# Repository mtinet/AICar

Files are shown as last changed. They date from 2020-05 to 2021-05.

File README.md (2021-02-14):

# AICar

### 아두이노 메가 사용 시 블루투스 내부 배선  
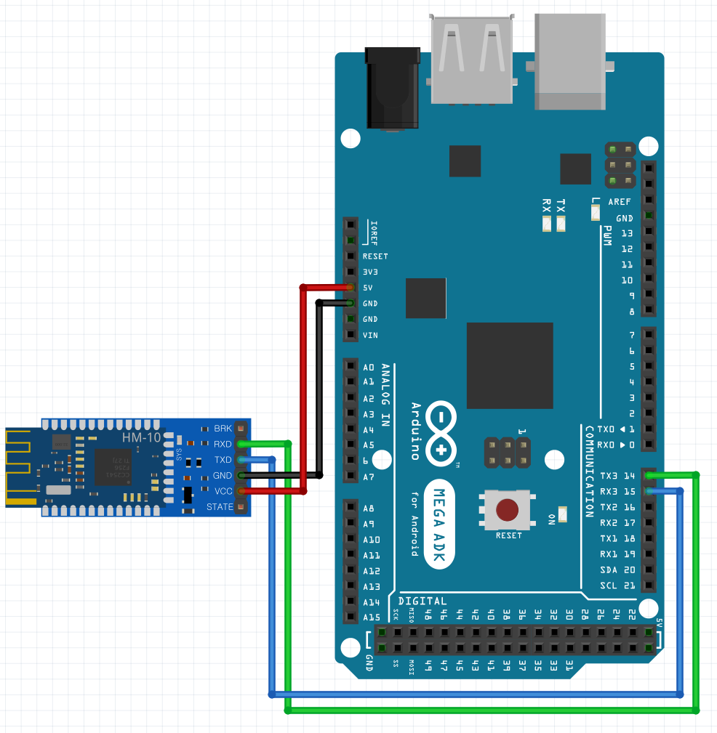
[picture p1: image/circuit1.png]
  

### 앱인벤터  
* [이미지 분류 학습](https://classifier.appinventor.mit.edu/)  
* [익스텐션 다운로드](https://mit-cml.github.io/extensions/) : PersonalImageClassifier, BLE 다운로드 받을 것  
* BLE 세팅 방법  
  
```
serviceUUID : 0000FFE0-0000-1000-8000-00805F9B34FB
name : 아두이노의 AT커맨드로 자기가 지정해 준 이름 입력  
```
* 아두이노 AT 커맨드 사용할 때 업로드 해야하는 코드, 블루투스 모듈(HM-10)이 다른 장치에 연결되지 않은 상태에서만 AT 커맨드가 적용됨, 아두이노의 시리얼 모니터 하단에 있는 옵션에서는 'line ending 없음' 또는 'Both NL & ER'을 선택하고, 통신속도는 9600보드레이트로 선택함  
```
void setup() {
  //통신 설정
  Serial.begin(9600); // 시리얼 통신(컴퓨터-USB케이블-아두이노 메가)
  Serial3.begin(9600); // 블루투스 통신(스마트폰 앱-블루투스-아두이노 메가)
  Serial.println("start");
}

void loop() {
  if (Serial3.available())        // 블루투스에서 데이터가 들어올 경우
    Serial.write(Serial3.read()); // 컴퓨터로 보냄
  if (Serial.available())         // 컴퓨터에서 데이터가 들어올 경우
    Serial3.write(Serial.read()); // 블루투스로 보냄
}
```

### 참고자료  
* [앱인벤터 코드 작성 참고자료](http://blog.naver.com/PostView.nhn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)  
* [앱인벤터, 아두이노 통신](http://sanguru.me/arduino009/) 
* [딕셔너리 결과물 보는 방법](http://ai2.appinventor.mit.edu/reference/blocks/dictionaries.html#get-value-at-key-path)  
* [BLE 세팅](http://www.martyncurrey.com/arduino-hm-10-and-app-inventor-2/#AI2)

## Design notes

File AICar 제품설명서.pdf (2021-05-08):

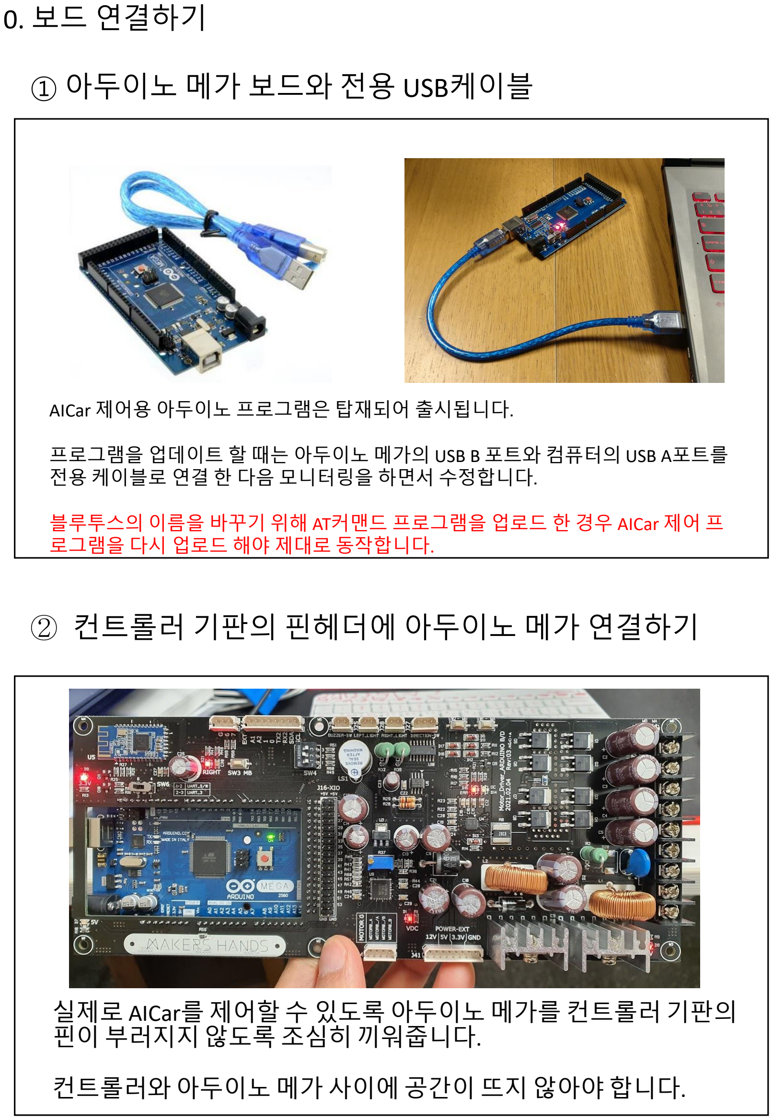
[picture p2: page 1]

### ② 컨트롤러 기판의 핀헤더에 아두이노 메가 연결하기

## ①②③④

0. 보드 연결하기

실제로 AICar를 제어할 수 있도록 아두이노 메가를 컨트롤러 기판의 핀이 부러지지 않도록 조심히 끼워줍니다.

컨트롤러와 아두이노 메가 사이에 공간이 뜨지 않아야 합니다.

AICar 제어용 아두이노 프로그램은 탑재되어 출시됩니다.

프로그램을 업데이트 할 때는 아두이노 메가의 USB B 포트와 컴퓨터의 USB A포트를 전용 케이블로 연결 한 다음 모니터링을 하면서 수정합니다.

블루투스의 이름을 바꾸기 위해 AT커맨드 프로그램을 업로드 한 경우 AICar 제어 프 로그램을 다시 업로드 해야 제대로 동작합니다.

### ① 아두이노 메가 보드와 전용 USB케이블

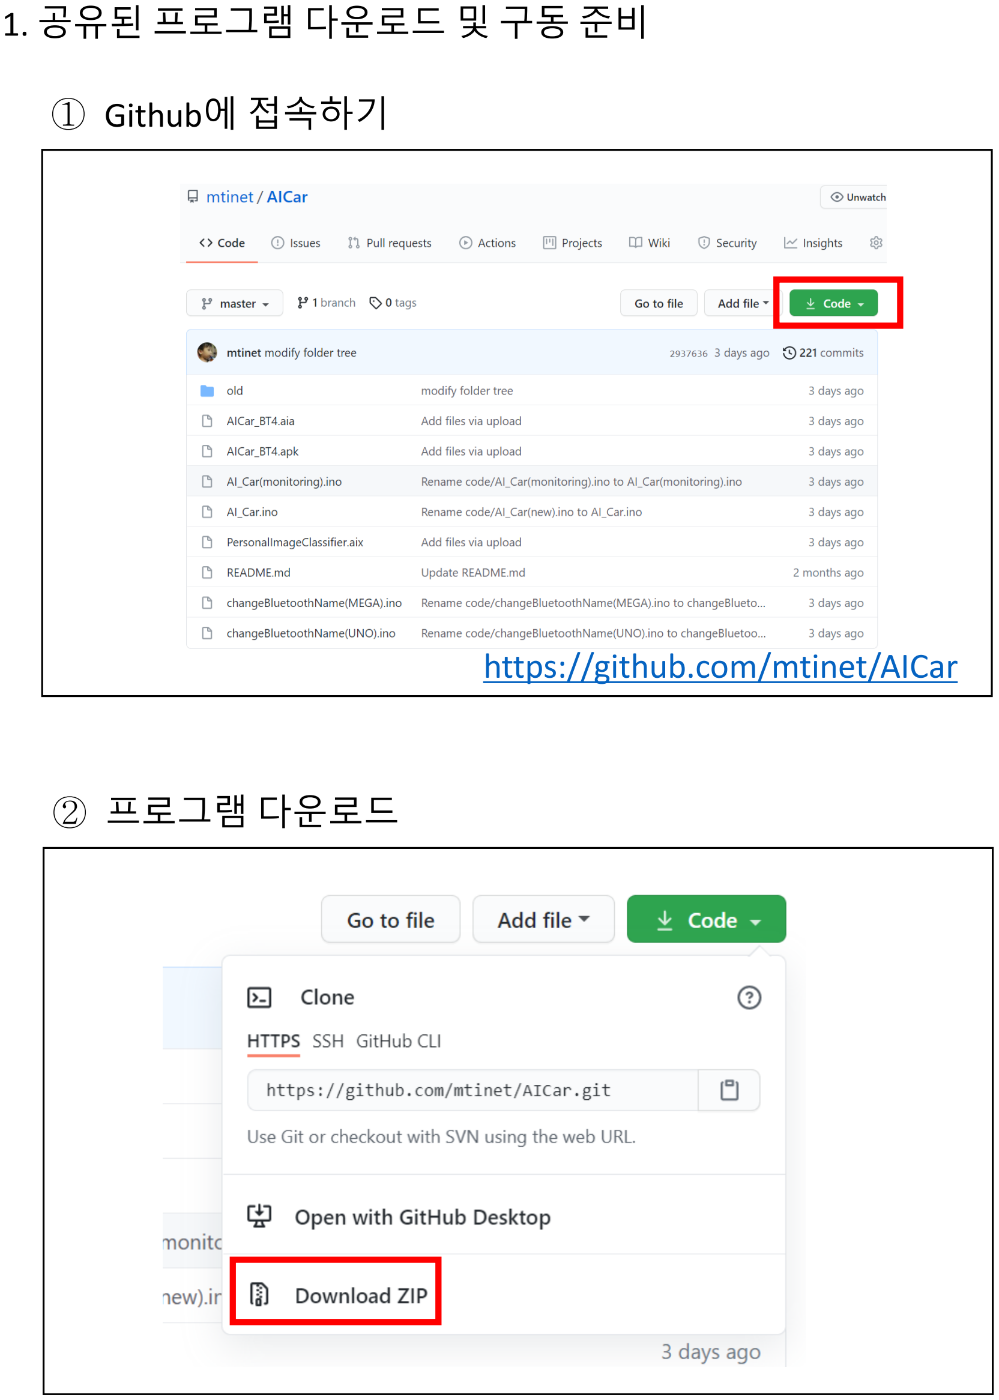
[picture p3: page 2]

① Github에 접속하기

### 1. 공유된 프로그램 다운로드 및 구동 준비

② 프로그램 다운로드

https://github.com/mtinet/AICar

### ③ 압축풀기

### ④ 바탕화면 선택

### 원하는 폴더를 지정하거나, 바탕화면을 선택함

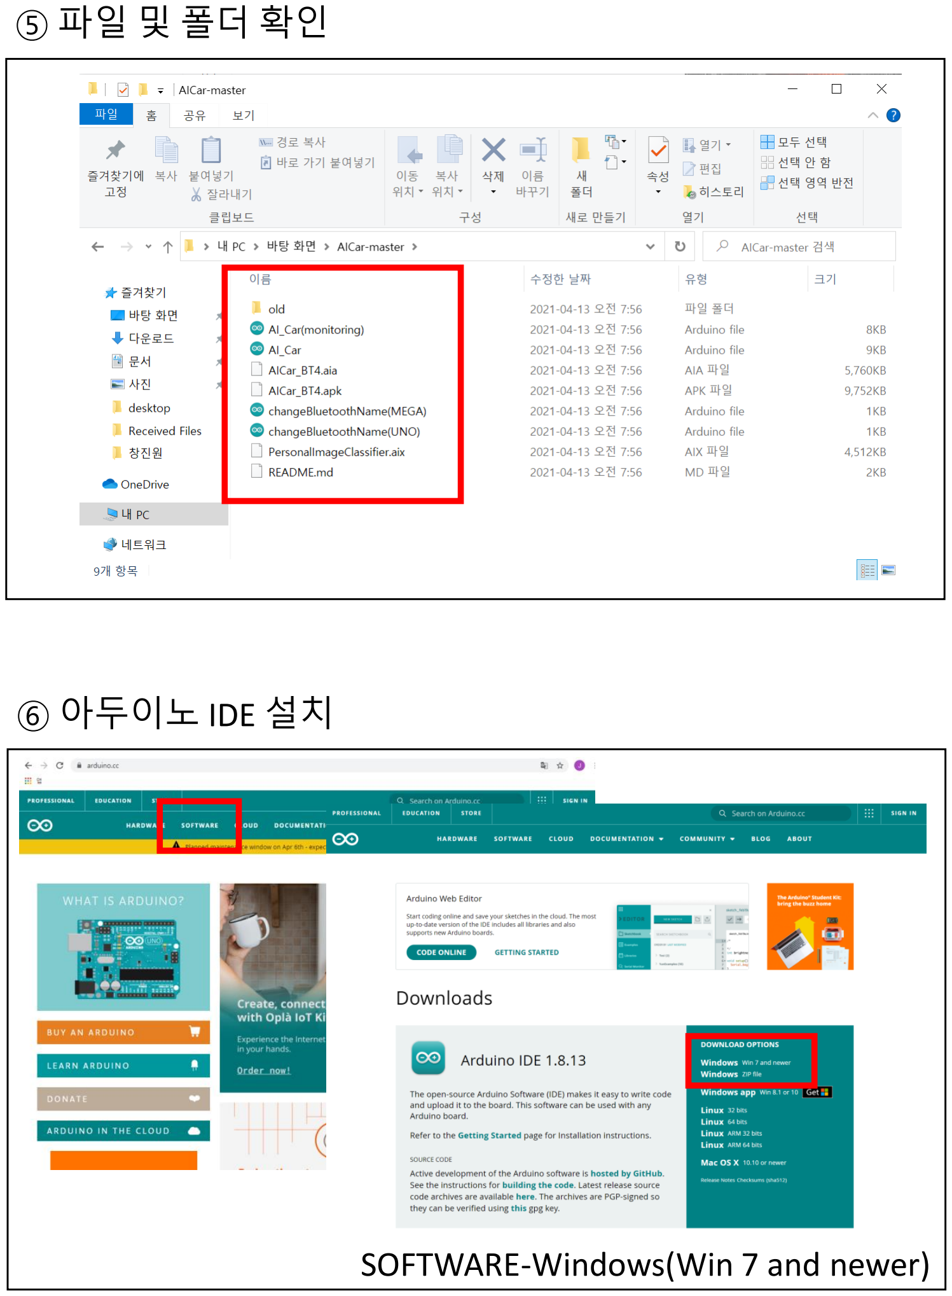
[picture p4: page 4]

### ⑤ 파일 및 폴더 확인

⑥ 아두이노 IDE 설치

SOFTWARE-Windows(Win 7 and newer)

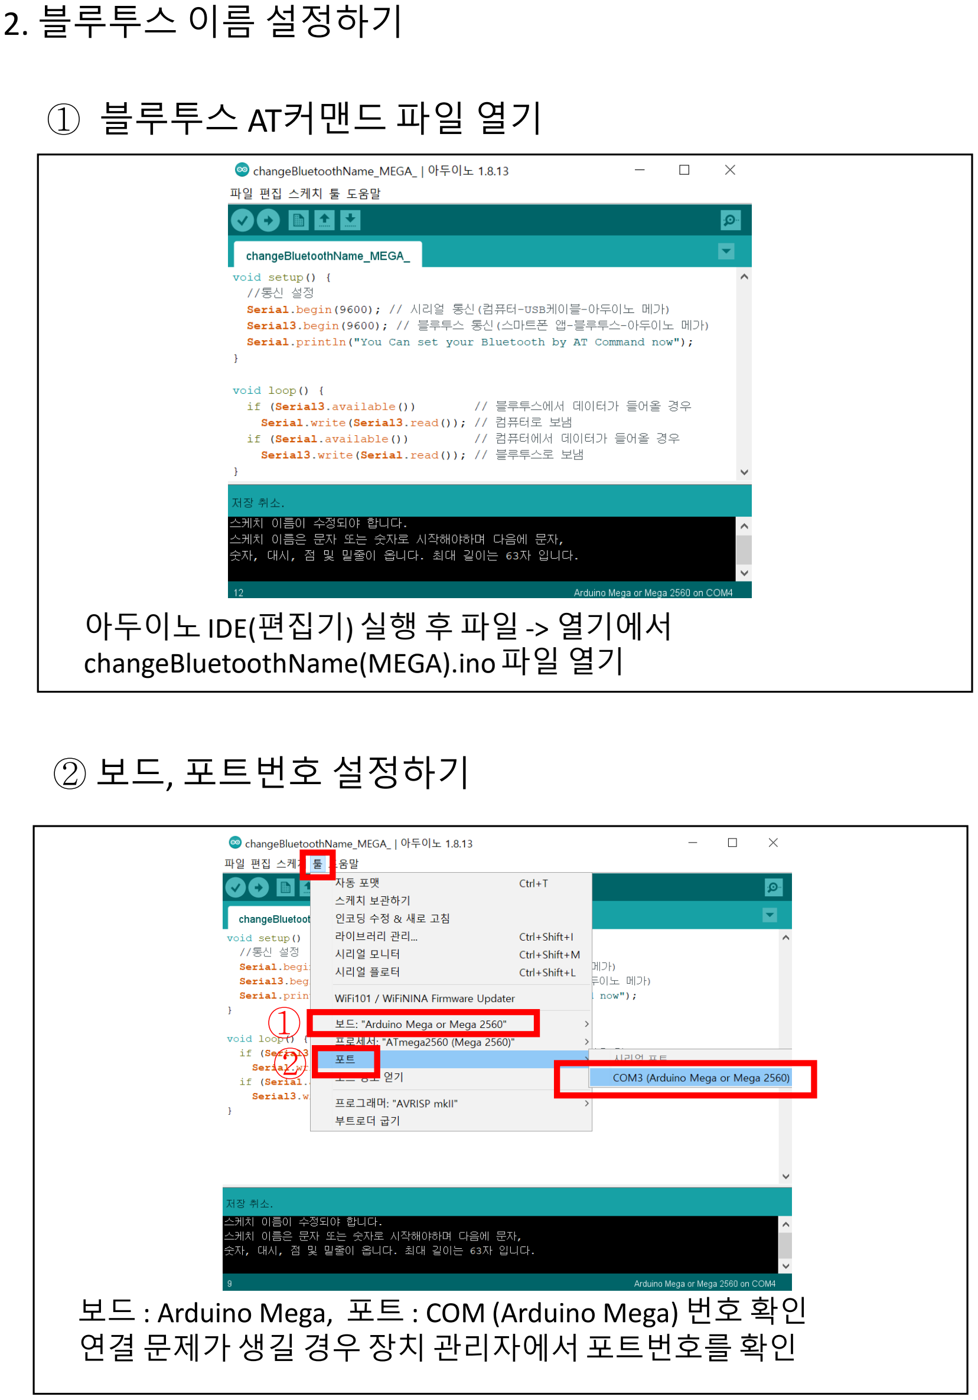
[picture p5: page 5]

### ① 블루투스 AT커맨드 파일 열기

② 보드, 포트번호 설정하기

보드 : Arduino Mega, 포트 : COM (Arduino Mega) 번호 확인 연결 문제가 생길 경우 장치 관리자에서 포트번호를 확인

②

①

아두이노 IDE(편집기) 실행 후 파일 -> 열기에서 changeBluetoothName(MEGA).ino 파일 열기

### 2. 블루투스 이름 설정하기

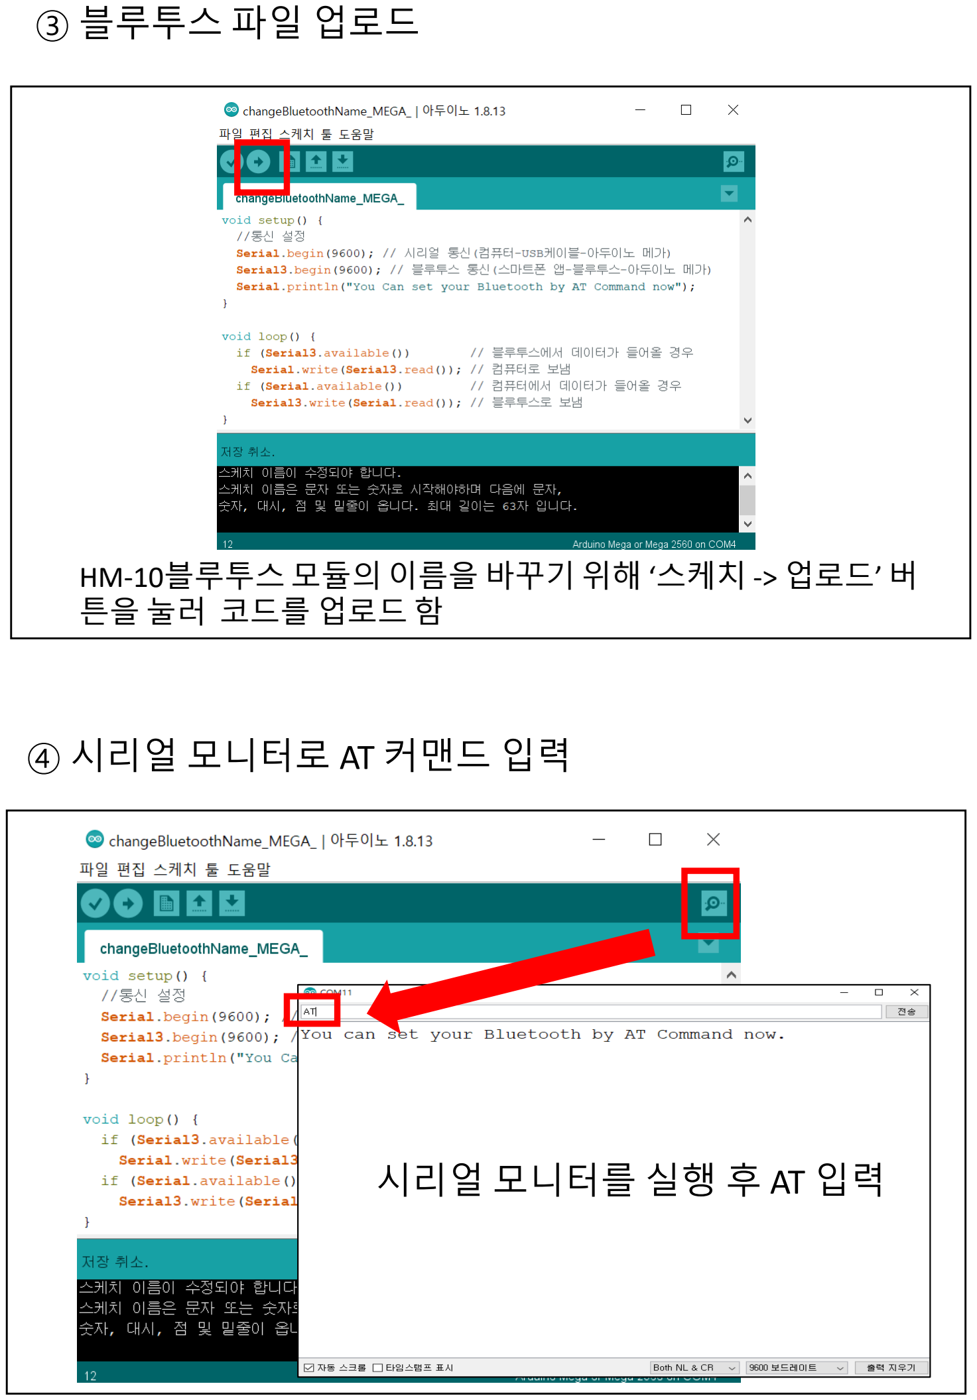
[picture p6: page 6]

③ 블루투스 파일 업로드

### ④ 시리얼 모니터로 AT 커맨드 입력

HM-10블루투스 모듈의 이름을 바꾸기 위해 ‘스케치 -> 업로드’ 버 튼을 눌러 코드를 업로드 함

### 시리얼 모니터를 실행 후 AT 입력

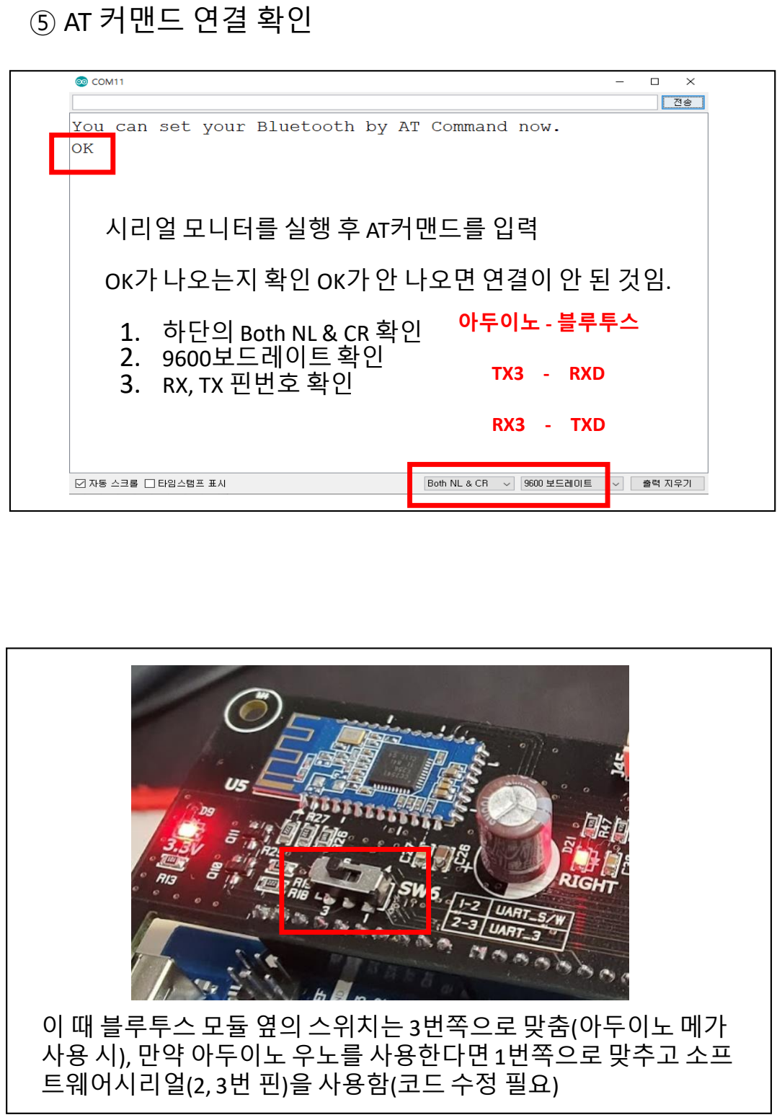
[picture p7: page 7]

### ⑤ AT 커맨드 연결 확인

시리얼 모니터를 실행 후 AT커맨드를 입력

OK가 나오는지 확인 OK가 안 나오면 연결이 안 된 것임.

1. 하단의 Both NL & CR 확인
2. 9600보드레이트 확인
3. RX, TX 핀번호 확인

이 때 블루투스 모듈 옆의 스위치는 3번쪽으로 맞춤(아두이노 메가 사용 시), 만약 아두이노 우노를 사용한다면 1번쪽으로 맞추고 소프 트웨어시리얼(2, 3번 핀)을 사용함(코드 수정 필요)

아두이노 - 블루투스

TX3 - RXD

RX3 - TXD

### ⑥ 블루투스 이름변경

### ⑦ 변경된 블루투스 이름 확인

MA4

MA4

AT+NAME이름을 통해 블루투스 모듈의 이름을 변경할 수 있습니다. (블루투스 이름 기본값은 MLT-BT05)

AT+NAMEMA4 라고 입력하면
(AT+NAME 뒤에 공백 제거)

블루투스 이름이 MA4 라고 검색됨

MA4

AT+NAME 명령어를 입력하면
현재 블루투스 모듈의 이름을
확인할 수 있음

### ⑧ 스마트폰에서 변경된 블루투스 이름 확인

변경된 블루투스 모듈의
이름이 스마트폰에서 검색되는
것을 확인할 수 있습니다.

검색이 잘 되면 따로 등록하지 않아도
앱을 통해 바로 연결 가능합니다.

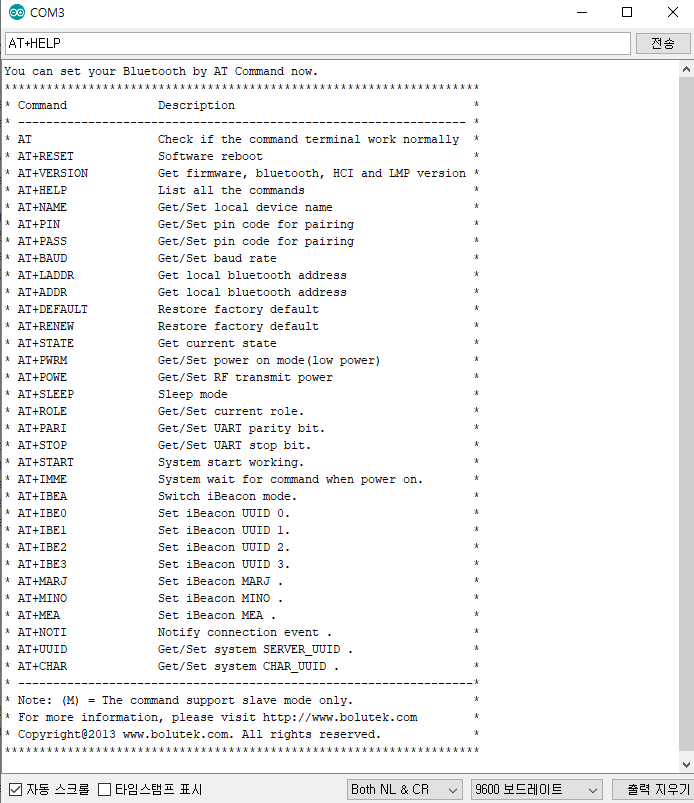
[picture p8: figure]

AT+HELP 명령어를 통해
AT Command로 설정할
수 있는 모든 기능을 확
인할 수 있습니다.

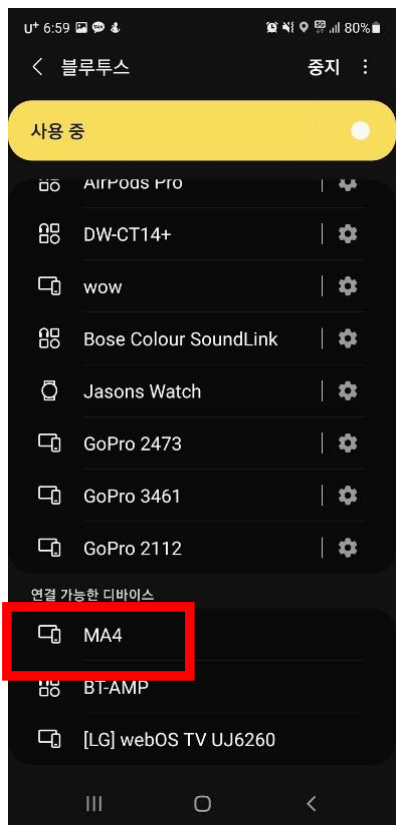
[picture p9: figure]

⑨ AT커맨드 도움말

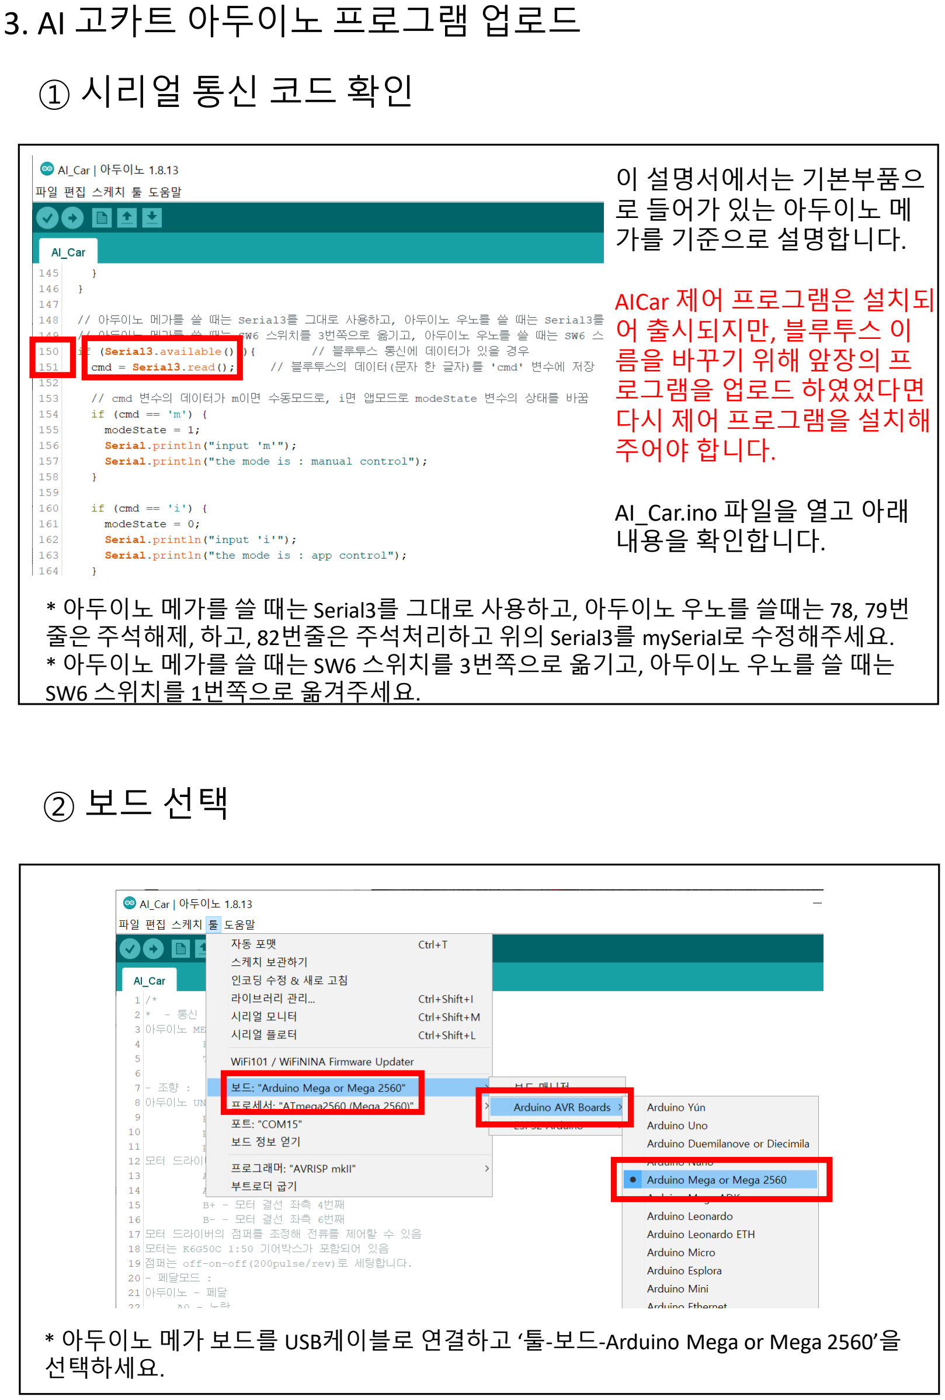
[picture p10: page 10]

### ① 시리얼 통신 코드 확인

이 설명서에서는 기본부품으
로 들어가 있는 아두이노 메
가를 기준으로 설명합니다.

AICar 제어 프로그램은 설치되
어 출시되지만, 블루투스 이
름을 바꾸기 위해 앞장의 프
로그램을 업로드 하였었다면
다시 제어 프로그램을 설치해
주어야 합니다.

AI_Car.ino 파일을 열고 아래
내용을 확인합니다.

② 보드 선택

* 아두이노 메가를 쓸 때는 Serial3를 그대로 사용하고, 아두이노 우노를 쓸때는 78, 79번 줄은 주석해제, 하고, 82번줄은 주석처리하고 위의 Serial3를 mySerial로 수정해주세요. * 아두이노 메가를 쓸 때는 SW6 스위치를 3번쪽으로 옮기고, 아두이노 우노를 쓸 때는 SW6 스위치를 1번쪽으로 옮겨주세요.

3. AI 고카트 아두이노 프로그램 업로드

* 아두이노 메가 보드를 USB케이블로 연결하고 ‘툴-보드-Arduino Mega or Mega 2560’을 선택하세요.

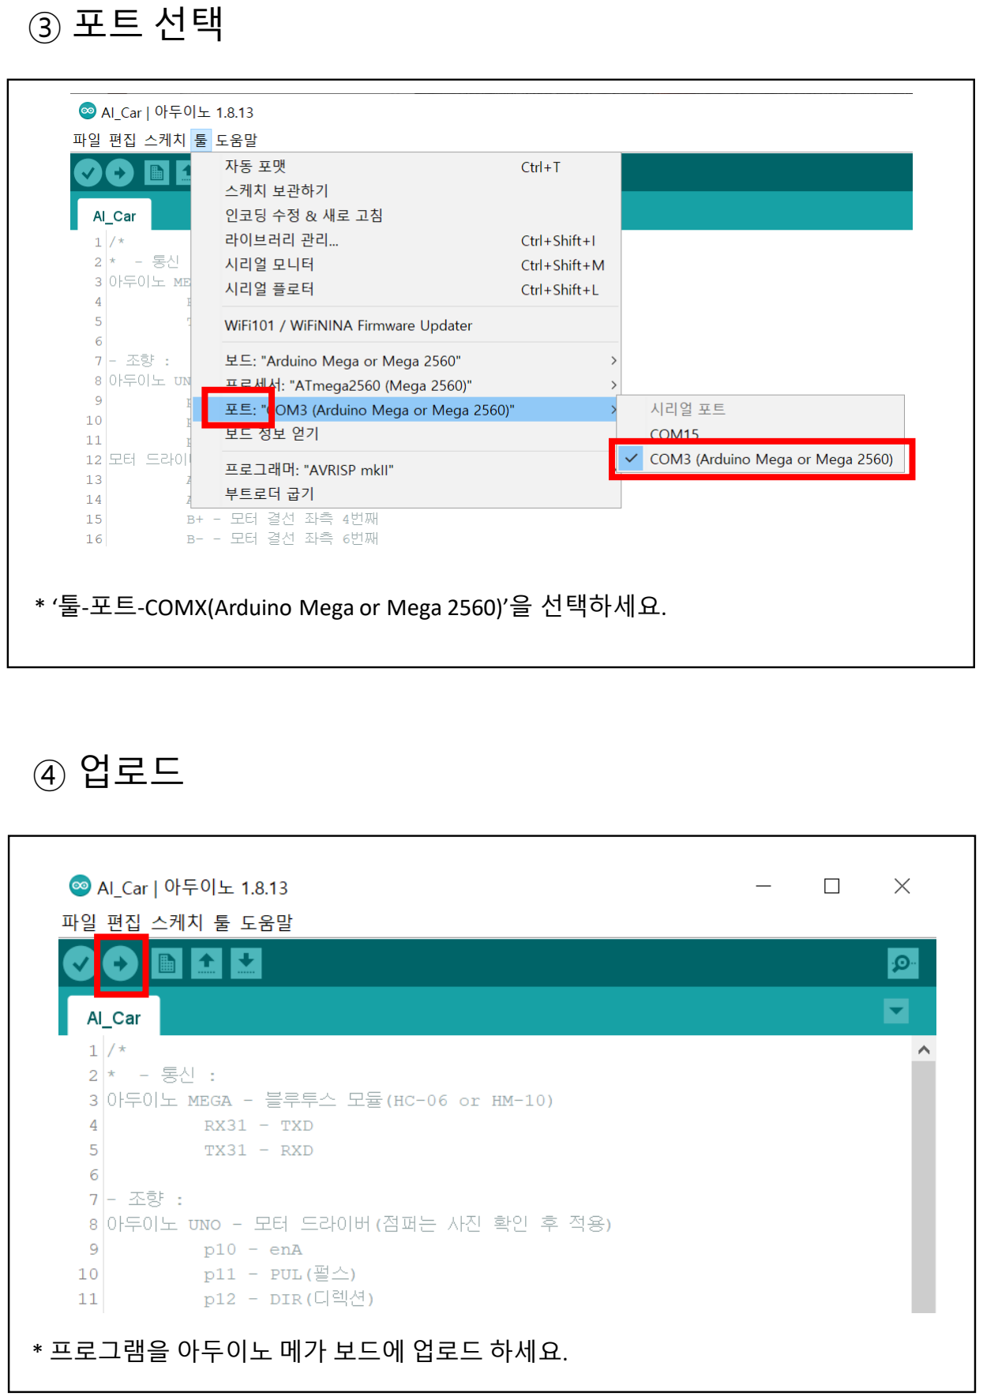
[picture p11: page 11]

③ 포트 선택

④ 업로드

* ‘툴-포트-COMX(Arduino Mega or Mega 2560)’을 선택하세요.

* 프로그램을 아두이노 메가 보드에 업로드 하세요.

### ① 시리얼 모니터링

### ② 전진, 후진 전환 버튼

시리얼 모니터를 실행

스위치를 전진 시

Forward: FFFF

스위치를 후진 시

Rear: RRRR

* 아두이노 IDE의 우측 상단에 있는 ‘시리얼 모니터 버튼’을 누르세요. * AICar의 기본 모드는 수동모드입니다.

### 사진수정할 것

4. AI 고카트 동작 확인_수동모드

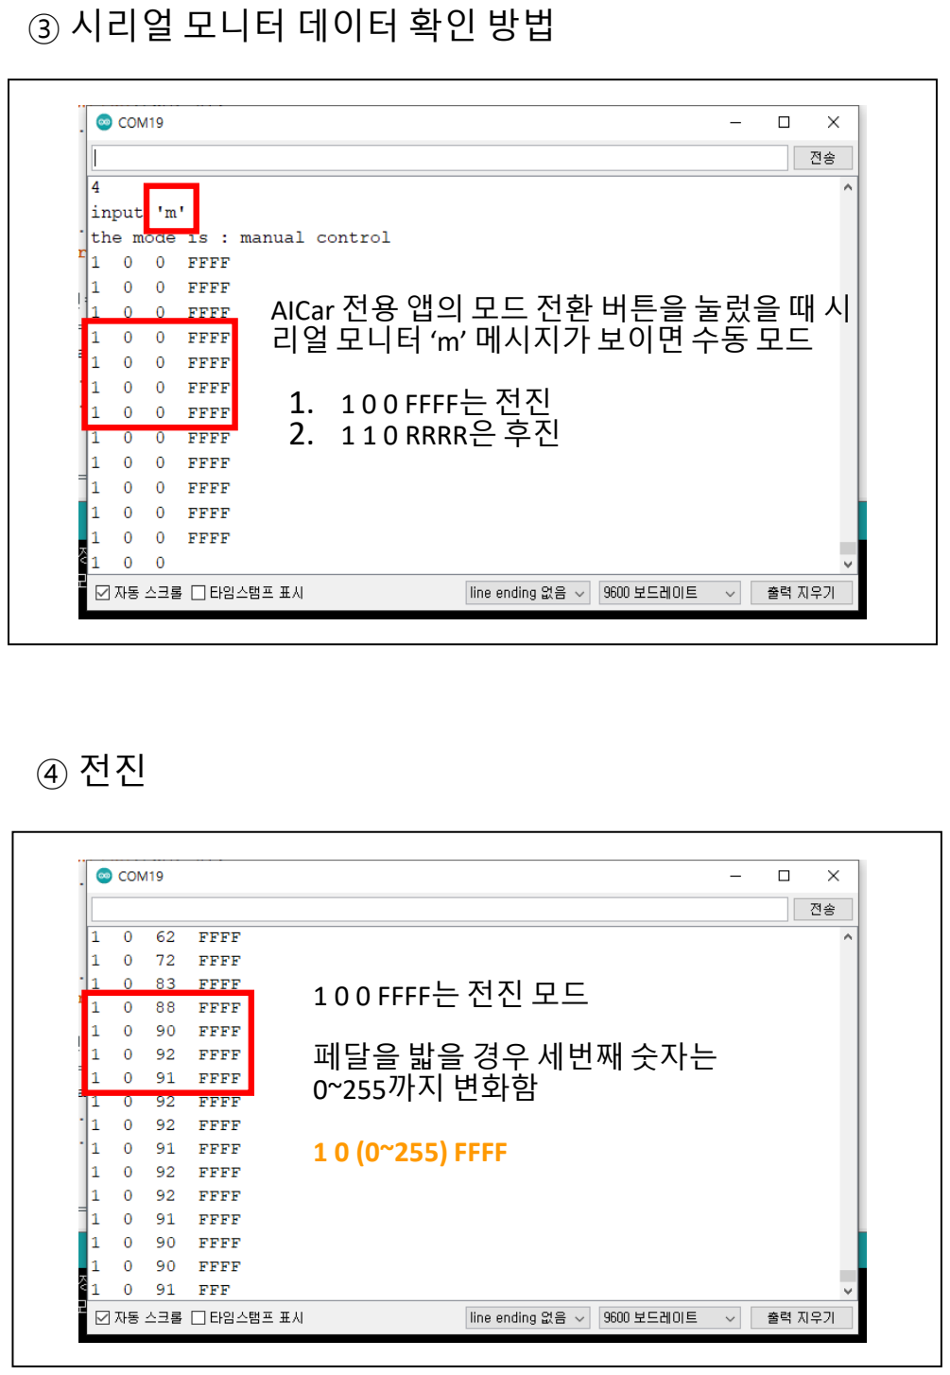
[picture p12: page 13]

### ③ 시리얼 모니터 데이터 확인 방법

AICar 전용 앱의 모드 전환 버튼을 눌렀을 때 시 리얼 모니터 ‘m’ 메시지가 보이면 수동 모드

1. 1 0 0 FFFF는 전진
2. 1 1 0 RRRR은 후진

### ④ 전진

1 0 0 FFFF는 전진 모드

페달을 밟을 경우 세번째 숫자는
0~255까지 변화함

1 0 (0~255) FFFF

### ⑤ 후진

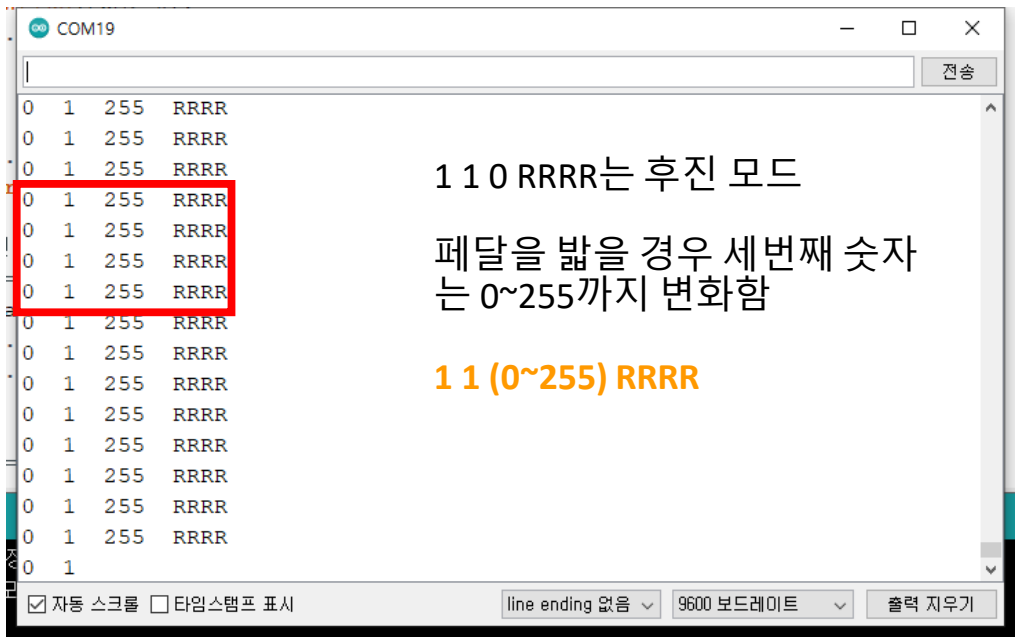
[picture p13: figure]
1 1 0 RRRR는 후진 모드; 페달을 밟을 경우 세번째 숫자 는 0~255까지 변화함; 1 1 (0~255) RRRR

⑥ 조향

수동모드로 조향을 할 때는 스
텝모터 케이블을 제거해주세요.

제거하지 않고 조향을 할 경우
스텝모터에 무리가 가고 조향이
잘 되지 않습니다.

### 스텝모터 케이블 사 진 추가

# http://appinventor.mit.edu/

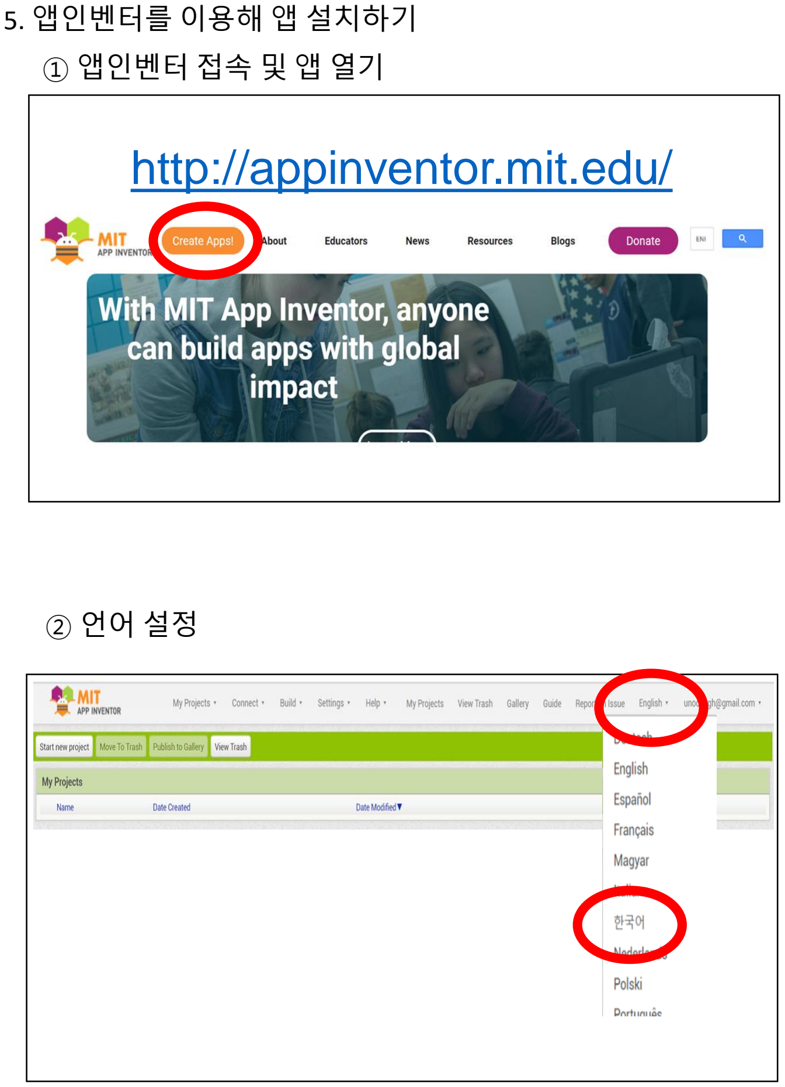
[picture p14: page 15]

### ① 앱인벤터 접속 및 앱 열기

### ② 언어 설정

### 5. 앱인벤터를 이용해 앱 설치하기

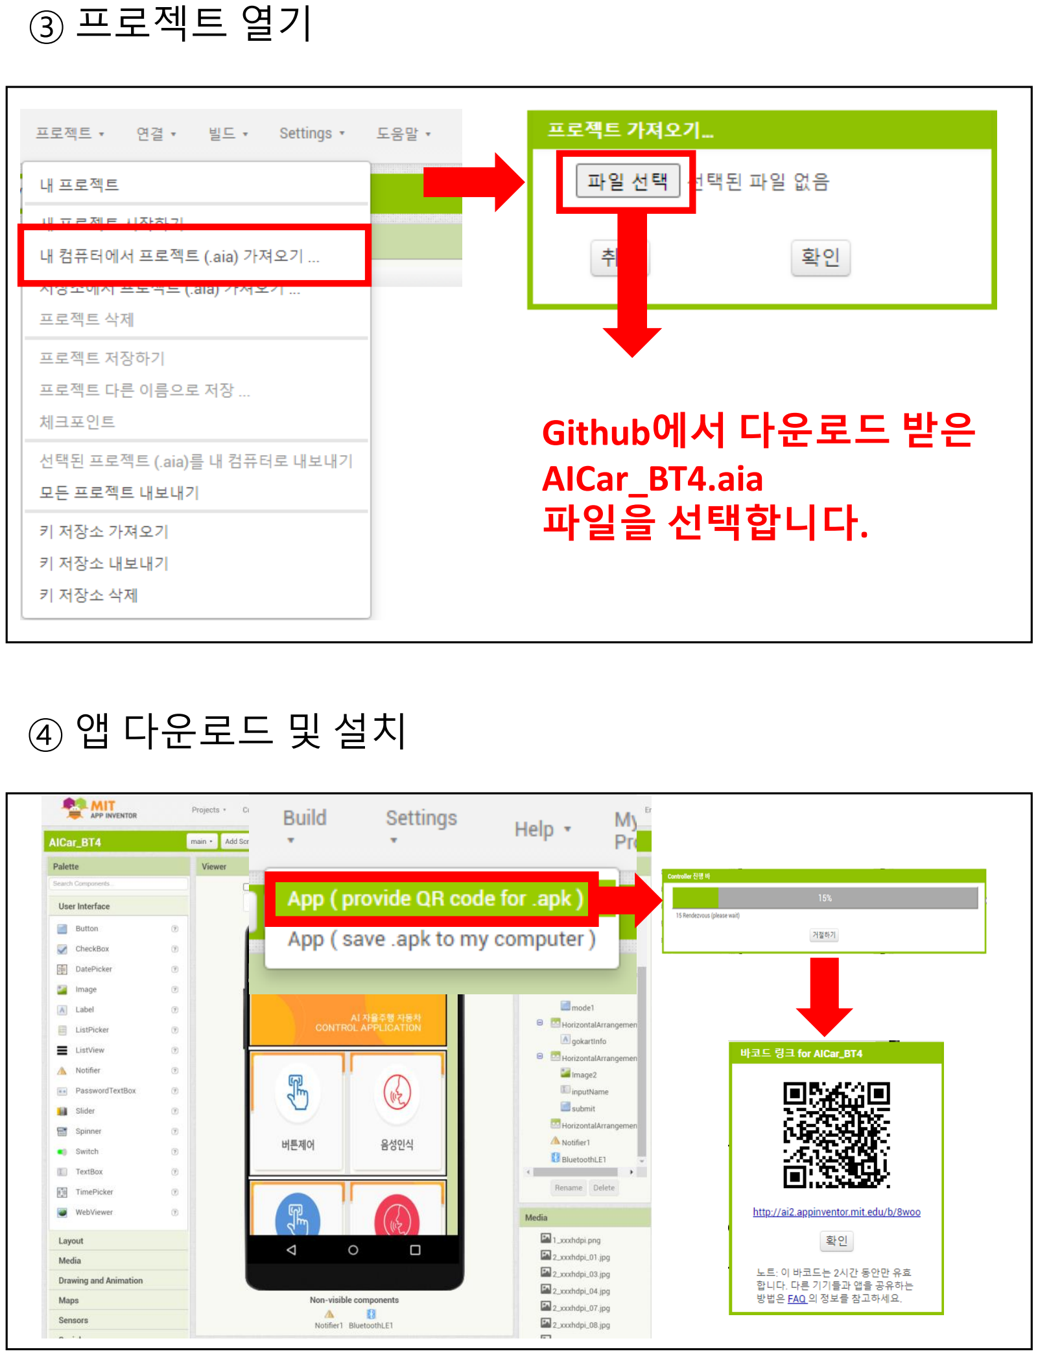
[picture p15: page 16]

③ 프로젝트 열기

Github에서 다운로드 받은
AICar_BT4.aia
파일을 선택합니다.

### ④ 앱 다운로드 및 설치

### ① 블루투스 연결

② 모드 전환

6. AI 고카트 동작 확인_전용앱모드

AICar 전용앱을 엽니다.

먼저 블루투스 이름을 입력하고
‘입력’ 버튼을 누르세요.

앱을 사용할 때는 항상 연결되었
다는 메시지가 나온 다음에 명령
버튼을 사용합니다.

블루투스가 연결되고 나
서 ‘모드바꾸기’버튼을 누
릅니다.

모드가 ‘앱모드’로 바뀌면
앱을 이용해 AICar를 조종
할 수 있습니다.

'앱모드'로 바꾸지 않으면
다른 버튼이 눌리지 않습
니다.

블루투스 연결이 되면 앱에 블루투스 이름과 함께 연결메시지가 나오며, 깜빡거 리던 블루투스의 LED가 켜진채로 유지되는 것을 확인할 수 있습니다.

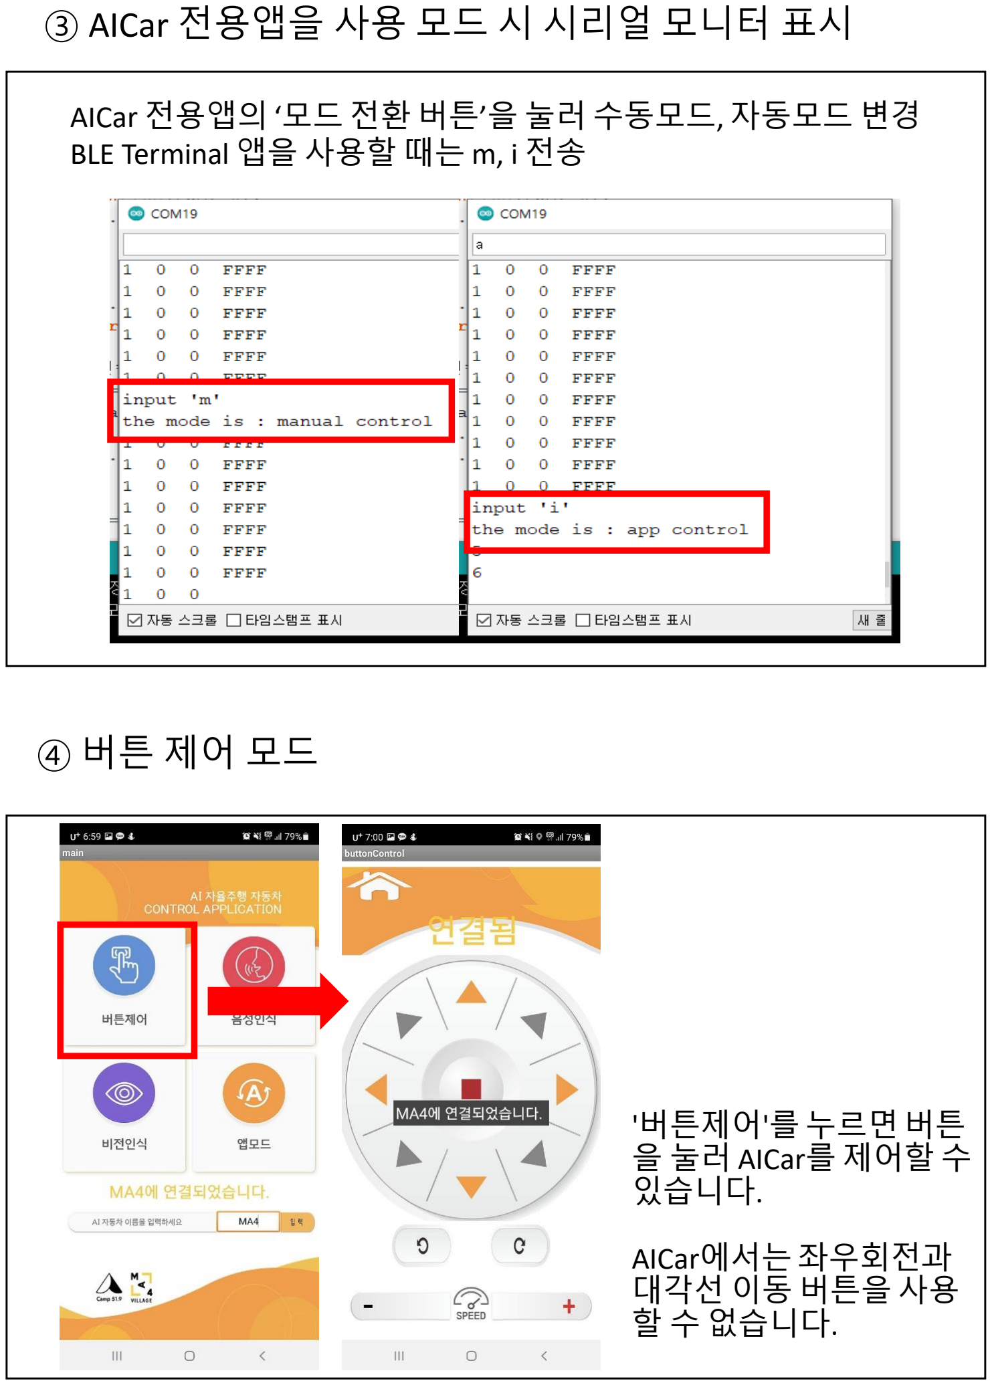
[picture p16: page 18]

### ③ AICar 전용앱을 사용 모드 시 시리얼 모니터 표시

④ 버튼 제어 모드

'버튼제어'를 누르면 버튼
을 눌러 AICar를 제어할 수
있습니다.

AICar에서는 좌우회전과
대각선 이동 버튼을 사용
할 수 없습니다.

AICar 전용앱의 ‘모드 전환 버튼’을 눌러 수동모드, 자동모드 변경 BLE Terminal 앱을 사용할 때는 m, i 전송

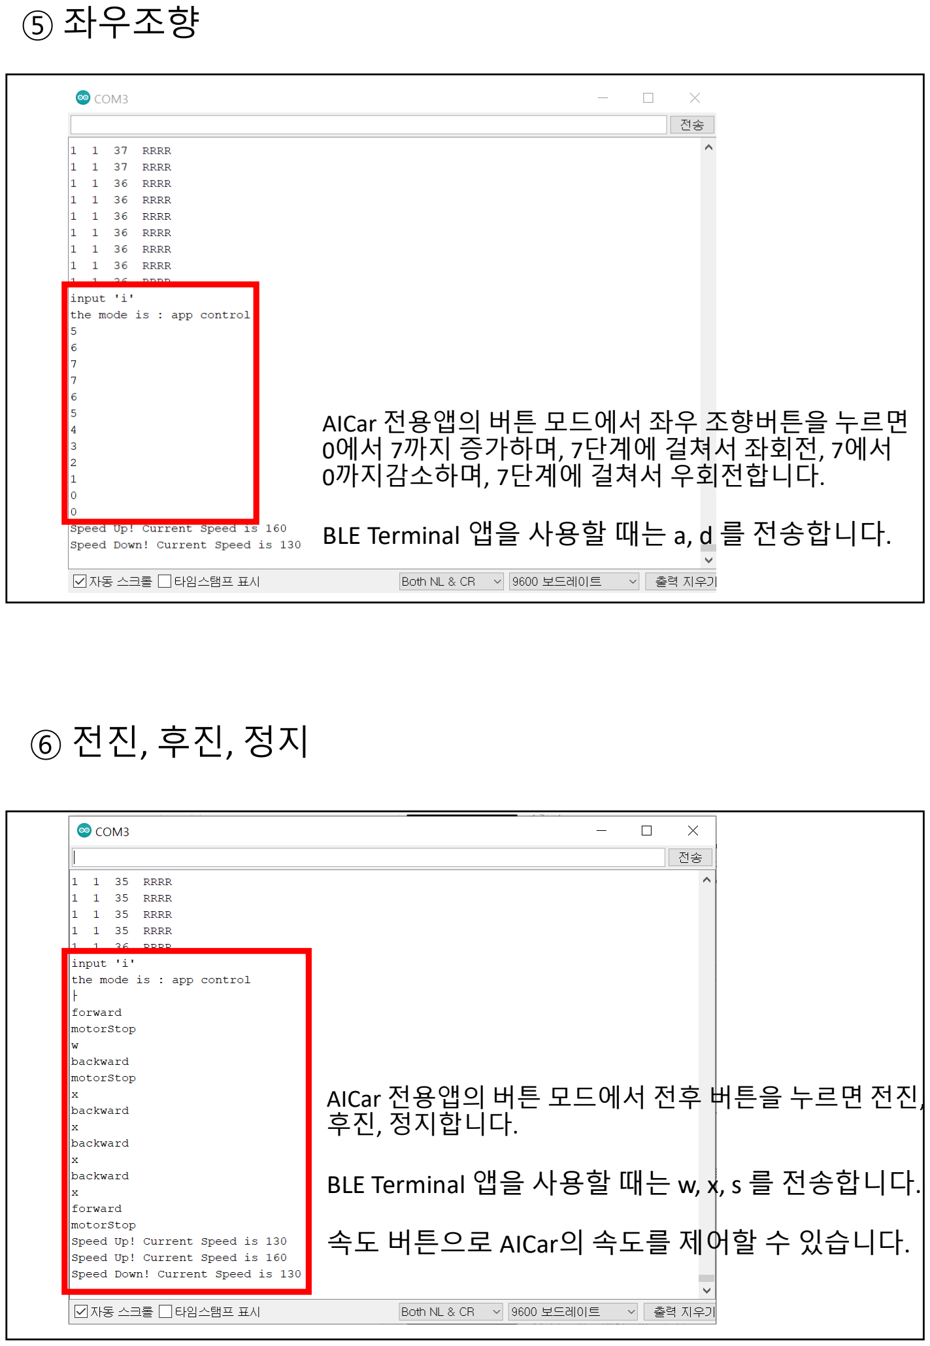
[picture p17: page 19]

⑤ 좌우조향

### ⑥ 전진, 후진, 정지

AICar 전용앱의 버튼 모드에서 좌우 조향버튼을 누르면 0에서 7까지 증가하며, 7단계에 걸쳐서 좌회전, 7에서 0까지감소하며, 7단계에 걸쳐서 우회전합니다.

BLE Terminal 앱을 사용할 때는 a, d 를 전송합니다.

AICar 전용앱의 버튼 모드에서 전후 버튼을 누르면 전진, 후진, 정지합니다.

BLE Terminal 앱을 사용할 때는 w, x, s 를 전송합니다.

속도 버튼으로 AICar의 속도를 제어할 수 있습니다.

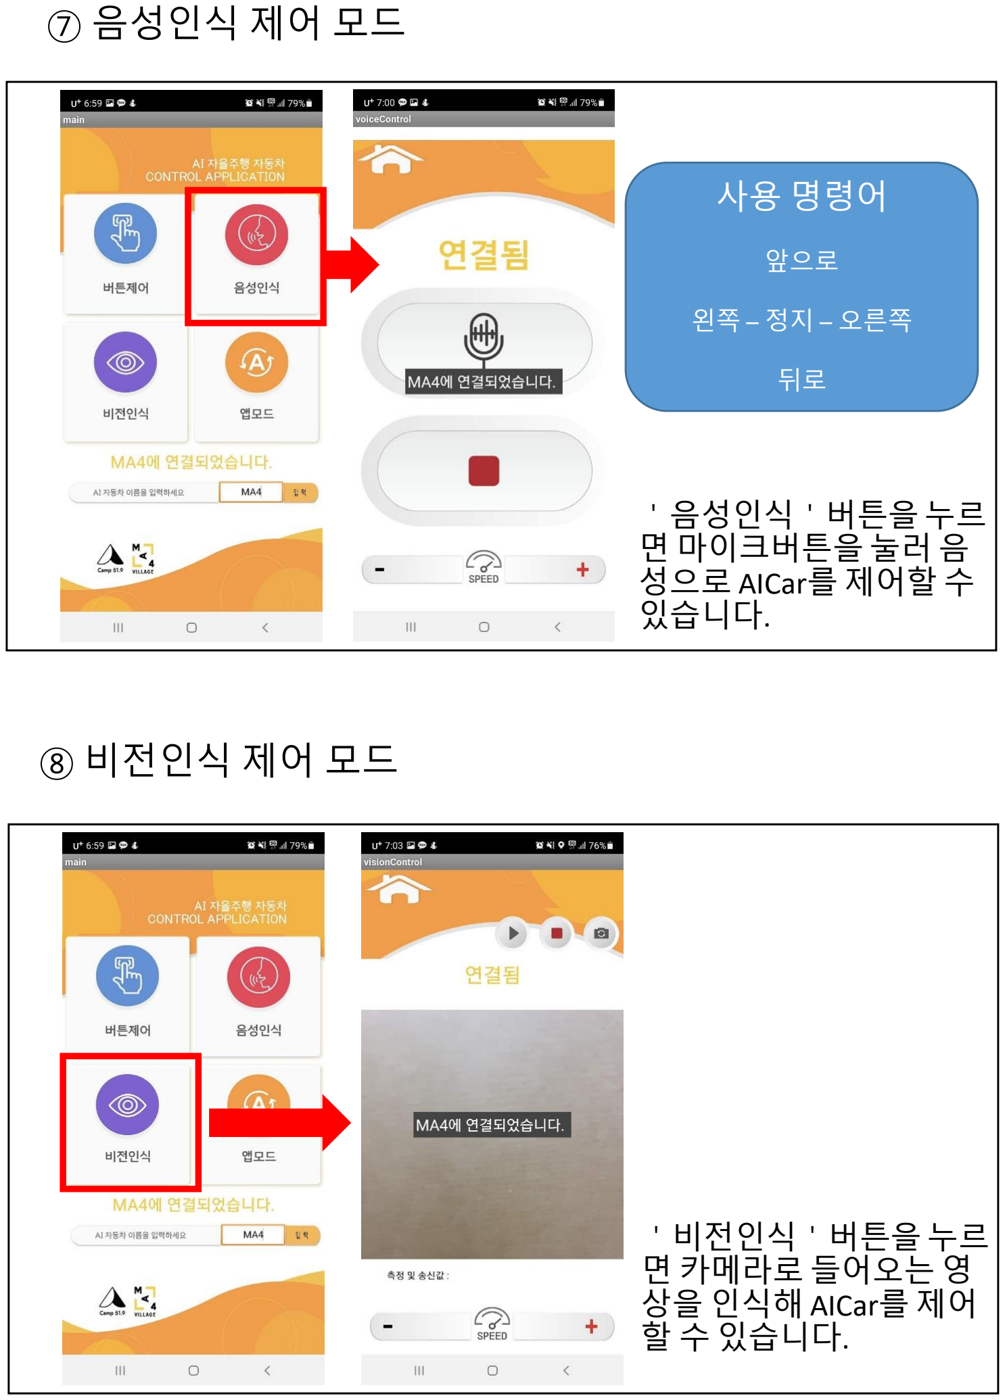
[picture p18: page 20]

### ⑦ 음성인식 제어 모드

### ⑧ 비전인식 제어 모드

＇음성인식＇버튼을 누르
면 마이크버튼을 눌러 음
성으로 AICar를 제어할 수
있습니다.

＇비전인식＇버튼을 누르
면 카메라로 들어오는 영
상을 인식해 AICar를 제어
할 수 있습니다.

사용 명령어

앞으로

왼쪽 – 정지 – 오른쪽

뒤로

### ⑨ 비전 인식 시작

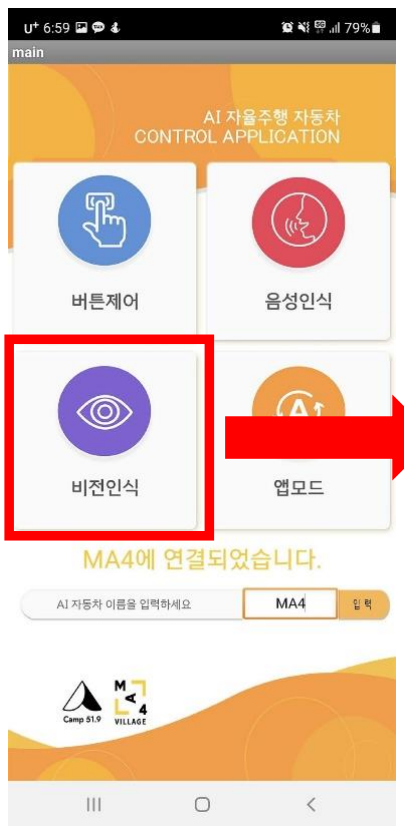
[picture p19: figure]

플레이 버튼을 누르면 첫번째
위치에 인식된 결과에 해당하
는 문자를 블루투스를 통해
송신합니다.

인식결과는 어떤 상황이 촬영
되든 학습된 결과물 중 가장
가깝게 인식되는 Label을 첫
번째 배열에 저장하고 관련
정보를 송신하도록 되어 있습
니다.

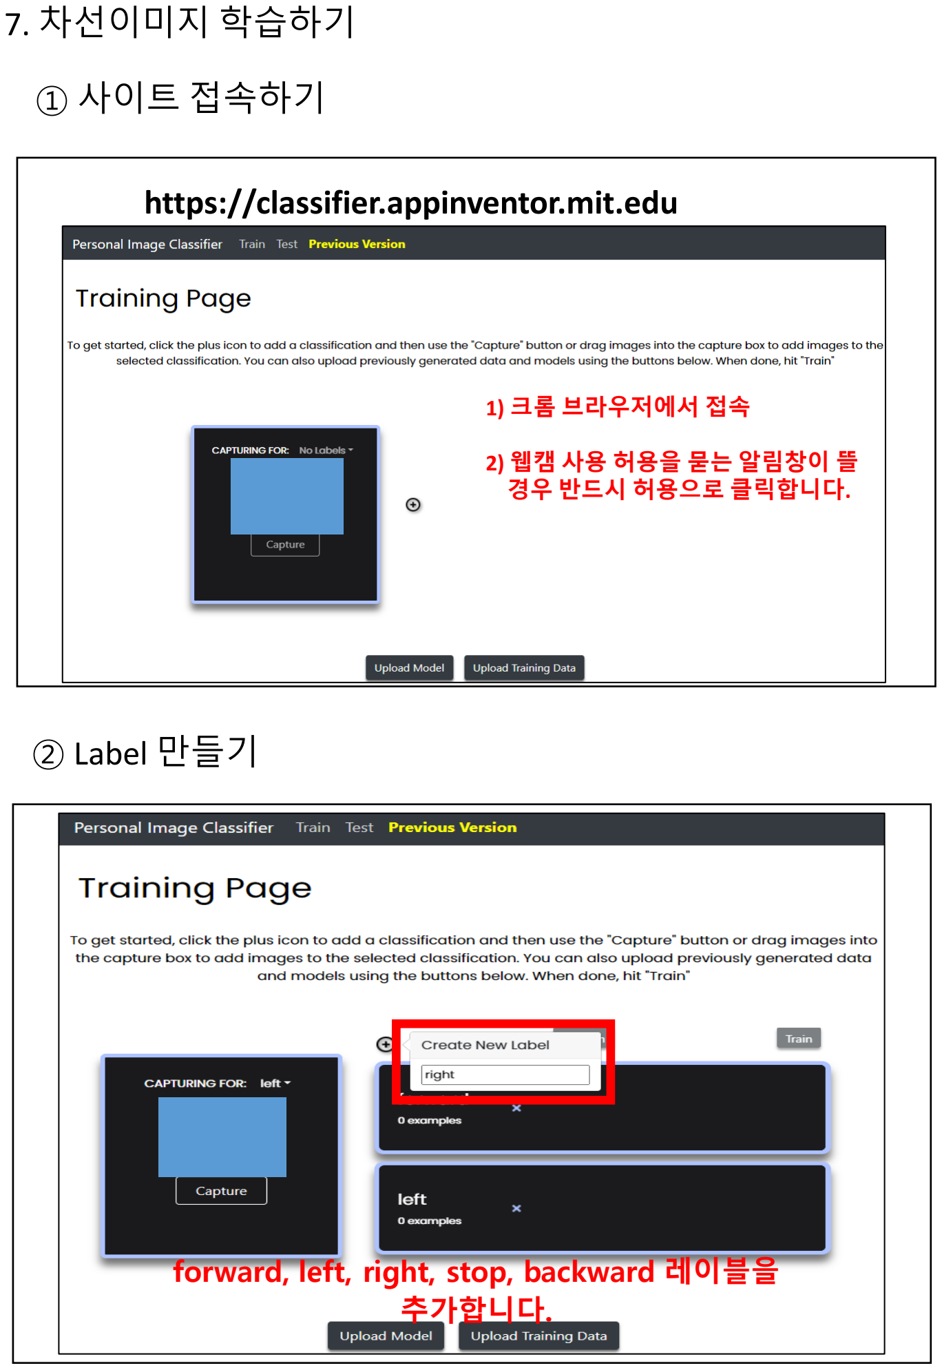
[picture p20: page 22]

1) 크롬 브라우저에서 접속
2) 웹캠 사용 허용을 묻는 알림창이 뜰
경우 반드시 허용으로 클릭합니다.

### ① 사이트 접속하기

② Label 만들기

https://classifier.appinventor.mit.edu

### 7. 차선이미지 학습하기

forward, left, right, stop, backward 레이블을 추가합니다.

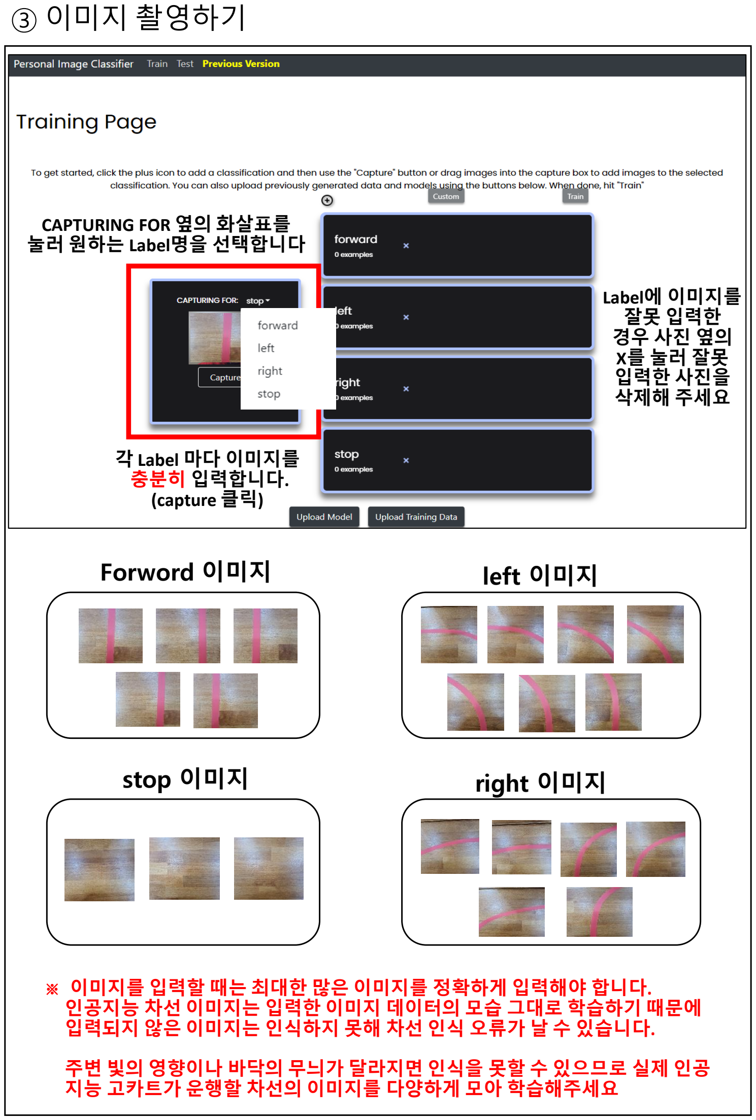
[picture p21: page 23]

### ③ 이미지 촬영하기

Forword 이미지 | left 이미지
stop 이미지 | right 이미지

※ 이미지를 입력할 때는 최대한 많은 이미지를 정확하게 입력해야 합니다. 인공지능 차선 이미지는 입력한 이미지 데이터의 모습 그대로 학습하기 때문에 입력되지 않은 이미지는 인식하지 못해 차선 인식 오류가 날 수 있습니다.

주변 빛의 영향이나 바닥의 무늬가 달라지면 인식을 못할 수 있으므로 실제 인공 지능 고카트가 운행할 차선의 이미지를 다양하게 모아 학습해주세요

각 Label 마다 이미지를
충분히 입력합니다.
(capture 클릭)

CAPTURING FOR 옆의 화살표를
눌러 원하는 Label명을 선택합니다

Label에 이미지를
잘못 입력한
경우 사진 옆의
X를 눌러 잘못
입력한 사진을
삭제해 주세요

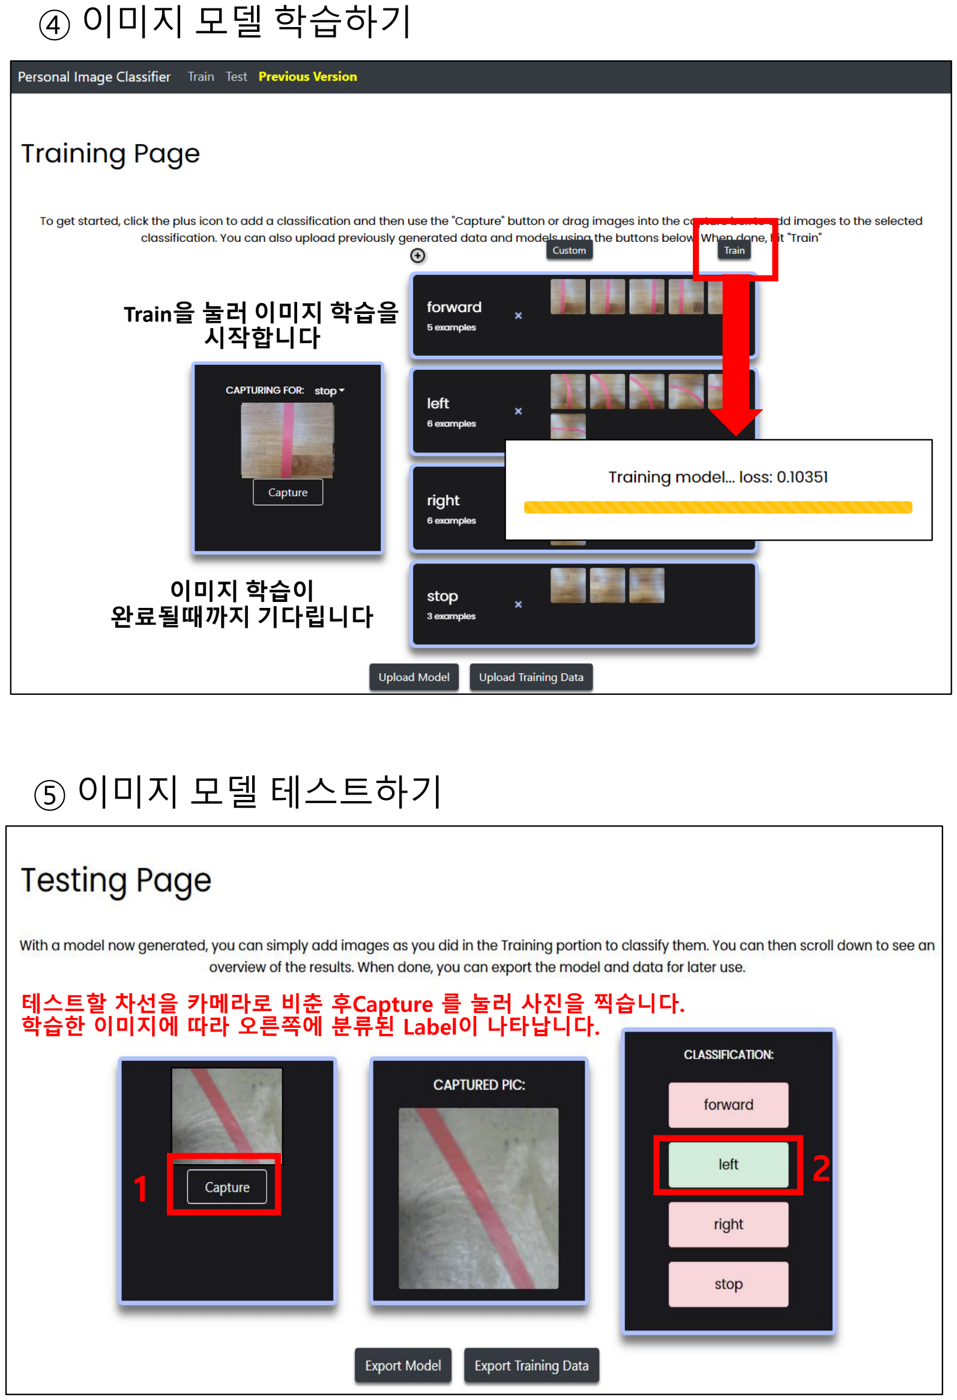
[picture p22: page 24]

### ④ 이미지 모델 학습하기

### ⑤ 이미지 모델 테스트하기

Train을 눌러 이미지 학습을
시작합니다

이미지 학습이
완료될때까지 기다립니다

테스트할 차선을 카메라로 비춘 후Capture 를 눌러 사진을 찍습니다. 학습한 이미지에 따라 오른쪽에 분류된 Label이 나타납니다.

1

2

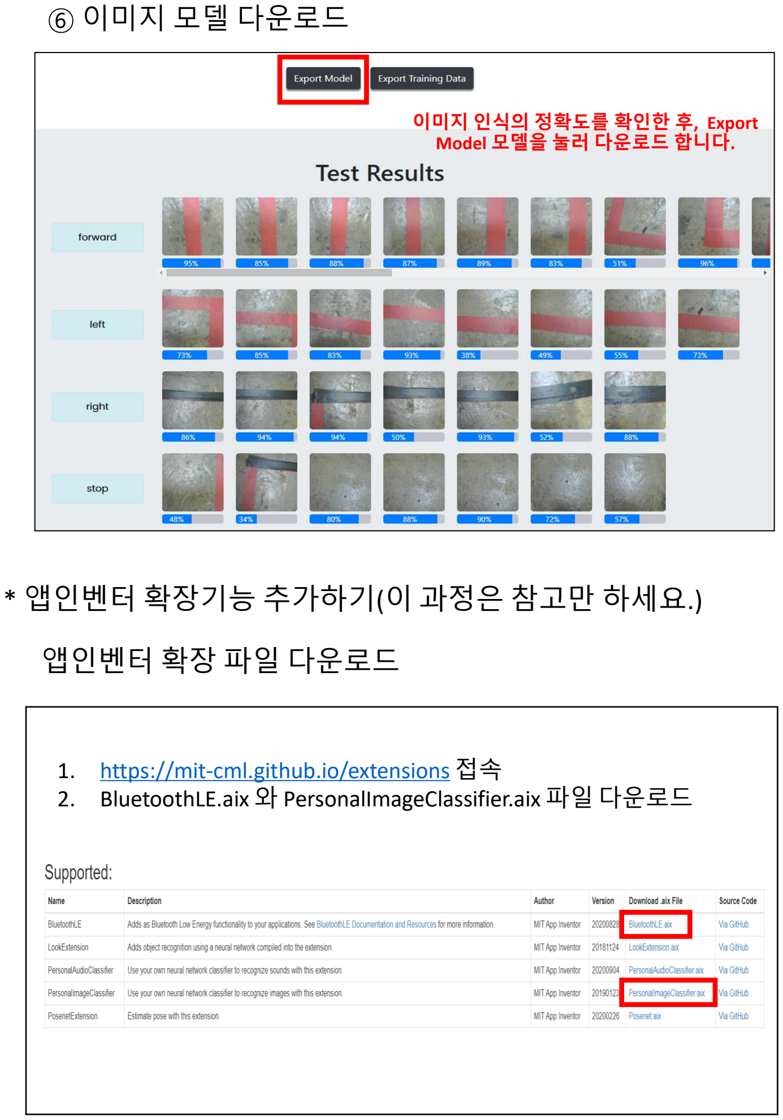
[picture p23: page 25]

### ⑥ 이미지 모델 다운로드

### 앱인벤터 확장 파일 다운로드

1. https://mit-cml.github.io/extensions 접속
2. BluetoothLE.aix 와 PersonalImageClassifier.aix 파일 다운로드

### * 앱인벤터 확장기능 추가하기(이 과정은 참고만 하세요.)

이미지 인식의 정확도를 확인한 후, Export Model 모델을 눌러 다운로드 합니다.

# http://appinventor.mit.edu/

### ① 앱인벤터 접속 및 앱 열기

### ② 언어 설정

### 8. 앱인벤터 학습모델 추가하기

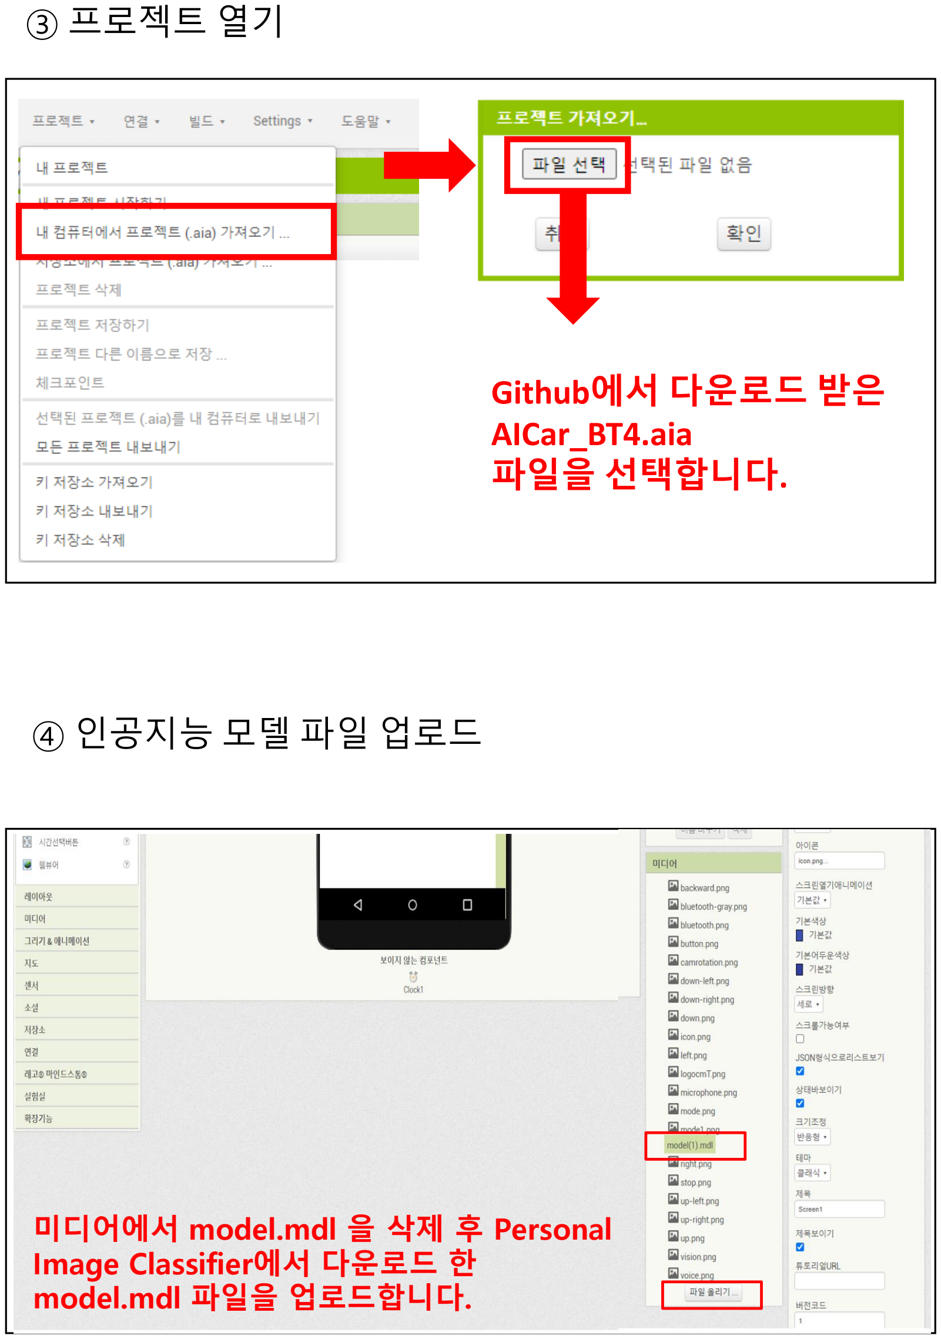
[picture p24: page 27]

③ 프로젝트 열기

### ④ 인공지능 모델 파일 업로드

Github에서 다운로드 받은
AICar_BT4.aia
파일을 선택합니다.

미디어에서 model.mdl 을 삭제 후 Personal Image Classifier에서 다운로드 한
model.mdl 파일을 업로드합니다.

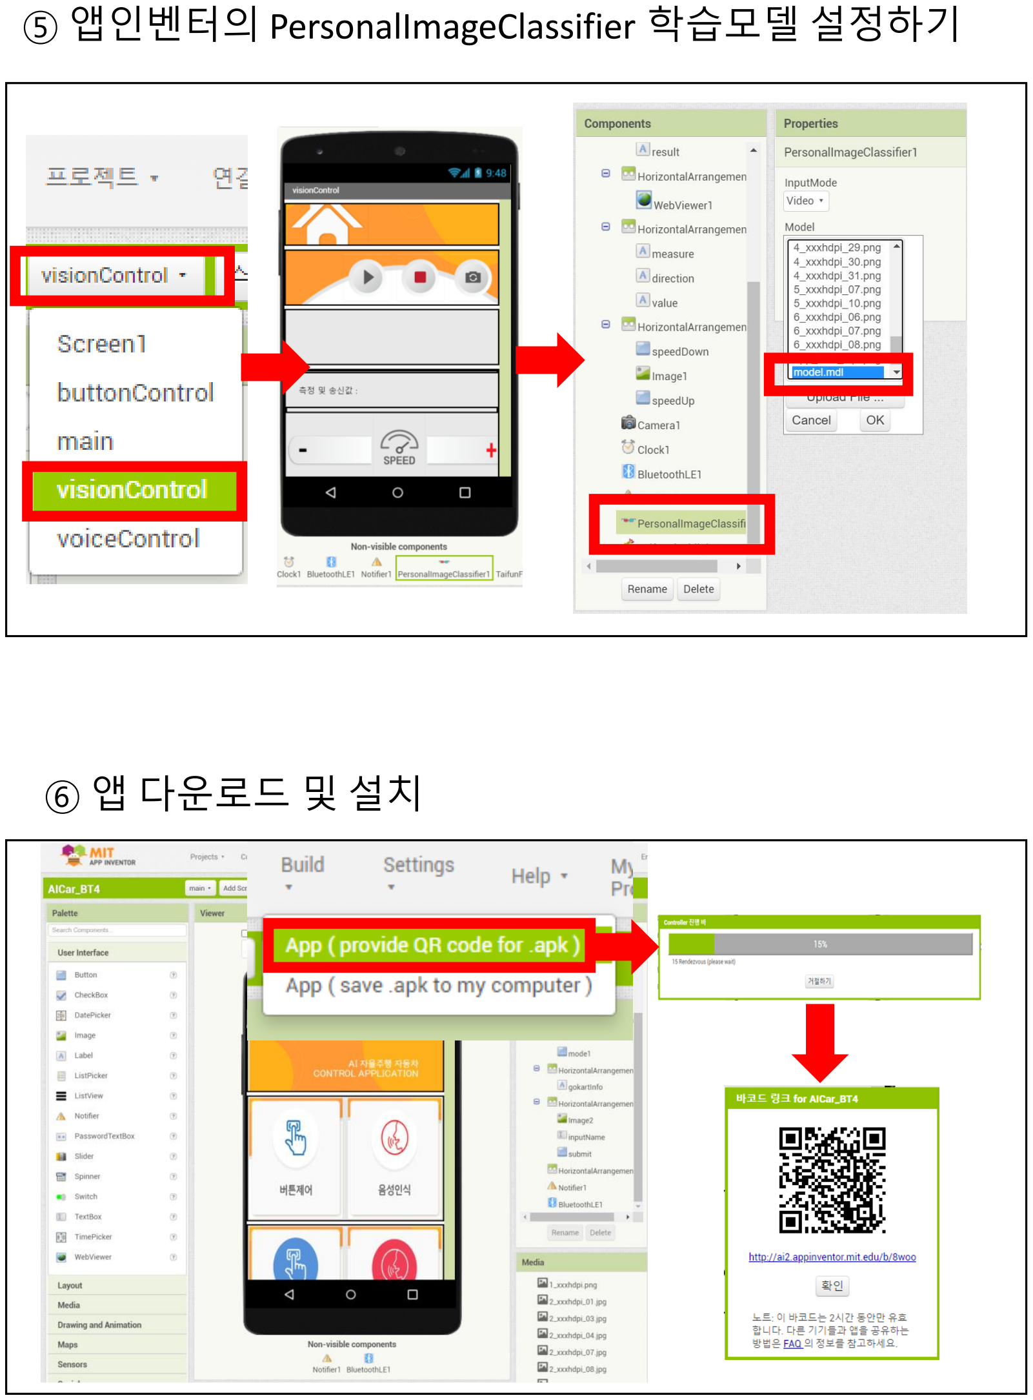
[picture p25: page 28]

⑤ 앱인벤터의 PersonalImageClassifier 학습모델 설정하기

### ⑥ 앱 다운로드 및 설치

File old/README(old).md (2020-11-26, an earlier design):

# AICar

### 1. 페달 테스트  
* [코드 링크](https://github.com/mtinet/AICar/blob/master/code/1.%20pedal.ino)  
* 테스트 이미지  
 

### 2. 전진, 후진 스위치 테스트  
* [코드 링크](https://github.com/mtinet/AICar/blob/master/code/2.%20switch.ino)  
* 테스트 이미지  
 

### 3. 블루투스 테스트  
* [코드 링크](https://github.com/mtinet/AICar/blob/master/code/3.%20bluetooth.ino)  
* 테스트 이미지  
  

### 4. 스텝모터 테스트  
* [코드 링크](https://github.com/mtinet/AICar/blob/master/code/4.%20stepMotor.ino)  
* 테스트 이미지  
  
 

### 5. DC모터 테스트  
* [코드 링크]()  
* 테스트 이미지  
  
 

### 6. 배터리 연결 및 비상정지 스위치 
* [코드 링크]()  
* 테스트 이미지  
 

### 7. 전체 테스트  
* [코드 링크](https://github.com/mtinet/AICar/blob/master/code/1.%20buttonVoiceVisionCar_miniboard.ino)  
  

### 모터 드라이버 구입  
* [[SMG-A] 12V/24V 7A 160W 듀얼 DC 모터 드라이버 모듈 [SZH-CH076]](https://www.devicemart.co.kr/goods/view?no=1361692)  
* [[ITM] TB6600 스테핑 모터드라이버](https://www.devicemart.co.kr/goods/view?no=10894384)  
* [Electric Bike/Scooter Foot Pedal Throttle Ebike Electric Tricycle Accelerator Pedal Speed Control Bicycle kit](https://www.aliexpress.com/item/32916923695.html?spm=a2g0o.cart.0.0.6cd43c00q48Iys&mp=1)  

### 앱인벤터  
* [이미지 분류 학습](https://classifier.appinventor.mit.edu/)  
* [익스텐션 다운로드](https://mit-cml.github.io/extensions/) : PersonalImageClassifier, BLE 다운로드 받을 것  
* BLE 세팅 방법  
  
```
serviceUUID : 0000FFE0-0000-1000-8000-00805F9B34FB
name : 아두이노의 AT커맨드로 자기가 지정해 준 이름 입력  
```
* 아두이노 AT 커맨드 사용할 때 업로드 해야하는 코드, 블루투스 모듈(HM-10)이 다른 장치에 연결되지 않은 상태에서만 AT 커맨드가 적용됨, 아두이노의 시리얼 모니터 하단에 있는 옵션에서는 'line ending 없음' 또는 'Both NL & ER'을 선택하고, 통신속도는 9600보드레이트로 선택함  
```
#include <SoftwareSerial.h>

SoftwareSerial mySerial(2, 3); // RX, TX

void setup() {
  Serial.begin(9600);
  while (!Serial) {
    ; 
  }

  Serial.println("Goodnight moon!");

  mySerial.begin(9600);
  mySerial.println("Hello, world?");
}

void loop() { 
  if (mySerial.available()) {
    Serial.write(mySerial.read());
  }
  if (Serial.available()) {
    mySerial.write(Serial.read());
  }
}
```

### 참고자료  
* [앱인벤터 코드 작성 참고자료](http://blog.naver.com/PostView.nhn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)  
* [앱인벤터, 아두이노 통신](http://sanguru.me/arduino009/) 
* [딕셔너리 결과물 보는 방법](http://ai2.appinventor.mit.edu/reference/blocks/dictionaries.html#get-value-at-key-path)  
* [BLE 세팅](http://www.martyncurrey.com/arduino-hm-10-and-app-inventor-2/#AI2)

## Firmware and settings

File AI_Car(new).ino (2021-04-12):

/* 
*  - 통신 :  
아두이노 MEGA - 블루투스 모듈(HC-06 or HM-10)  
         RX31 - TXD  
         TX31 - RXD  
         
- 조향 :  
아두이노 UNO - 모터 드라이버(점퍼는 사진 확인 후 적용)  
         p10 - enA 
         p11 - PUL(펄스)  
         p12 - DIR(디렉션)  
모터 드라이버 - 스텝모터(2번, 5번 미사용)  
         A+ - 모터 결선 좌측 1번째  
         A- - 모터 결선 좌측 3번째  
         B+ - 모터 결선 좌측 4번째  
         B- - 모터 결선 좌측 6번째  
모터 드라이버의 점퍼를 조정해 전류를 제어할 수 있음  
모터는 K6G50C 1:50 기어박스가 포함되어 있음  
점퍼는 off-on-off(200pulse/rev)로 세팅합니다. 
- 페달모드 :
아두이노 - 페달
     A0 - 노랑
     p7  - 스위치-전진
     p6  - 스위치-후진
- 구동 :  
아두이노 MEGA - 모터 드라이버  
전진후진(P8) - dir입력(모터 회전 방향)  
PWM출력(p9) - PWM입력(파워)  
*/

// 소프트웨어 시리얼은 아두이노 우노를 사용할 때는 아래 두 줄을 주석해제 합니다.
//#include <SoftwareSerial.h>
//SoftwareSerial mySerial(2, 3); // RX, TX

// 스텝 모터 제어
const int enA = 10;  // 구동 여부 결정
const int stepPin = 11; // 스텝 펄스
const int dirPinLR = 12;  // 좌우 회전
const int rst = 5; // 리셋, LOW 상태로 유지함

const int STEPS_PER_REV = 400; // 모터 2회전, 점퍼는 off-on-off로 세팅함(200pulse/rev)

int rotateLimit = 4;

// 드라이브 모터 제어
const int DIR = 8; // 파워
const int PWM = 9; // 신호 1 

int valocity = 100;

// 페달 제어_전진, 후진 스위치 센싱
int pedalF = 6;
boolean pedalFVal = 0;

int pedalB = 7;
boolean pedalBVal = 0;

const int ground = 4;

// 페달 제어_페달 센싱
const int pedalSensor = A0;
int pedalVal = 0;

// 수동 모드, 앱 제어모드 변경, 0은 앱제어모드, 1은 수동 모드
boolean modeState = 1;

// 속도값 초기화
int i = 0;

// 입력 문자, 입력 문자 백업
char cmd = "";
char cmdM = "";

void setup() {
  //모니터링을 위한 시리얼 통신 설정
  Serial.begin(9600); // 시리얼 통신
  
  //mySerial은 소프트웨어 시리얼입니다. 아두이노 우노를 사용할 때 주석을 해제해주세요.
  //mySerial.begin(9600); // 블루투스 통신  

  //Serial3는 아두이노 메가를 사용할 때 사용하는 시리얼입니다. 아두이노 우노를 사용하면 주석처리 하세요.
  Serial3.begin(9600);           

  // 스텝모터 핀 모드 설정
  pinMode(dirPinLR,OUTPUT);
  pinMode(stepPin,OUTPUT); 
  pinMode(enA, OUTPUT);
  digitalWrite(enA, HIGH);
  pinMode(rst, OUTPUT);
  digitalWrite(rst, LOW);

  // 드라이브모터 핀 모드 설정
  pinMode(PWM,OUTPUT); 
  pinMode(DIR, OUTPUT);
         
  // 페달모드 전진 후진 신호
  pinMode(pedalF, INPUT_PULLUP);
  pinMode(pedalB, INPUT_PULLUP);
  pinMode(ground, OUTPUT);
  digitalWrite(ground, LOW);

  Serial.println("AI Go-Kart is Ready!");
}

void loop() {
  //  modestate가 1이면 페달제어 모드로 수행
  if(modeState == 1) {       
    // 전진, 후진 스위치 값 저장
    pedalFVal = digitalRead(pedalF);
    pedalBVal = digitalRead(pedalB);

    // 페달값 센싱-매핑-한계범위설정
    pedalVal = analogRead(pedalSensor);
    pedalVal = map(pedalVal, 230, 850, 0, 255);
    pedalVal = constrain(pedalVal, 0, 255);

    // 페달 값 변화 시리얼 모니터 링
    Serial.print(pedalFVal);
    Serial.print("  ");
    Serial.print(pedalBVal);
    Serial.print("  ");
    Serial.print(pedalVal);
    Serial.print("  ");

    // 페달 신호가 0이면 브레이킹
    if (pedalVal == 0) {
      digitalWrite(DIR,LOW);   
      analogWrite(PWM, 0);
      delay(100);
    }

    // 전진, 후진 스위치 값에 따른 페달 동작
    if (pedalFVal == 1 && pedalBVal == 1) {
      digitalWrite(DIR,HIGH); 
      analogWrite(PWM, pedalVal);
      Serial.println("RRRR");
    } else if (pedalFVal == 1 && pedalBVal == 0) {
      digitalWrite(DIR,LOW);
      analogWrite(PWM, pedalVal);
      Serial.println("FFFF");
    } else {
      digitalWrite(DIR,LOW);  
      analogWrite(PWM, 0);
      Serial.println("SSSS");
    }
  }

  // 아두이노 메가를 쓸 때는 Serial3를 그대로 사용하고, 아두이노 우노를 쓸 때는 Serial3를 mySerial로 수정해주세요. 
  // 아두이노 메가를 쓸 때는 SW6 스위치를 3번쪽으로 옮기고, 아두이노 우노를 쓸 때는 SW6 스위치를 1번쪽으로 옮겨주세요.
  if (Serial3.available() ){        // 블루투스 통신에 데이터가 있을 경우
    cmd = Serial3.read();     // 블루투스의 데이터(문자 한 글자)를 'cmd' 변수에 저장
  
    // cmd 변수의 데이터가 m이면 수동모드로, i면 앱모드로 modeState 변수의 상태를 바꿈
    if (cmd == 'm') {
      modeState = 1;
      Serial.println("input 'm'");
      Serial.println("the mode is : manual control");
    }
    
    if (cmd == 'i') {
      modeState = 0;
      Serial.println("input 'i'");
      Serial.println("the mode is : app control");
    }    
    
    // modestate가 0이면 앱제어 모드로 수행
    if (modeState == 0) {
      if (cmd == 'w' ){               // 만약 w가 입력되면 이전 입력값'cmdM'을 확인하고, cmdM이 w이면 전진유지, 아니면 천천히 가속하여 전진
        Serial.println(cmdM);
        if(cmdM == 'w'){
          forward();
        } else {
          i = 0;
          forward();
        }
        cmdM = 'w';
      } else if ( cmd == 'x') {        // 만약 x가 입력되면 이전 입력값'cmdM'을 확인하고, cmdM이 x이면 후진유지, 아니면 천천히 가속하여 후진
        Serial.println(cmdM);
        if(cmdM == 'x') {
          backward();
        } else {
          i = 0;
          backward();
        }
        cmdM = 'x';
      } else if ( cmd == 'a' ) {       // 아니고 만약 'cmd' 변수의 데이터가 a면 좌회전
        right();
      } else if ( cmd == 'd' ) {       // 아니고 만약 'cmd' 변수의 데이터가 d면 우회전
        left();
      } else if ( cmd == 's' ) {       // 아니고 만약 'cmd' 변수의 데이터가 s면 정지
        motorStop();
      } else if ( cmd == 'o' ) {       // 아니고 만약 'cmd' 변수의 데이터가 o면 속도 줄이기
        valocity -= 30;
        if (valocity < 30) {
          valocity = 30;
        }
        Serial.print("Speed Down! Current Speed is ");
        Serial.println(valocity);
      } else if ( cmd == 'p' ) {       // 아니고 만약 'cmd' 변수의 데이터가 p면 속도 높이기
        valocity += 30;
        if (valocity > 250) {
          valocity = 250;
        }
        Serial.print("Speed Up! Current Speed is ");
        Serial.println(valocity);
      }
    }
  }
}



void left() {
  // 조향 모터가 '반시계방향'으로 회전하도록 신호부여
  digitalWrite(dirPinLR,HIGH); 
  
  if (rotateLimit > 0) {
    // 1000마이크로초 주기로 모터 축이 1.5회전하는 코드
    // 1:50 기어박스 내장되어 있으므로, 모터 1회전에 바퀴 7.2도 회전함
    // 따라서, 모터가 1.5회전하면 바퀴가 10.8도 회전함
    for(int x = 0; x < STEPS_PER_REV*1.5; x++) {
      digitalWrite(enA,HIGH);
      digitalWrite(stepPin,HIGH);
      delayMicroseconds(500);
      digitalWrite(stepPin,LOW);
      delayMicroseconds(500); 
    }
    rotateLimit = rotateLimit - 1;
  } else {
    rotateLimit = 0;
  }
  Serial.println(rotateLimit);
}

void right() {
  // 조향 모터가 '시계방향'으로 회전하도록 신호부여
  digitalWrite(dirPinLR,LOW); 
  
  if (rotateLimit < 7) {
    for(int x = 0; x < STEPS_PER_REV*1.5; x++) {
      digitalWrite(enA,HIGH);
      digitalWrite(stepPin,HIGH);
      delayMicroseconds(500);
      digitalWrite(stepPin,LOW);
      delayMicroseconds(500); 
    }
    rotateLimit = rotateLimit + 1;
  } else {
    rotateLimit = 7;
  }
  Serial.println(rotateLimit);
}

void forward() {
  //드라이브 모터가 앞으로 회전하도록 신호부여
  digitalWrite(DIR,LOW); 
  analogWrite(PWM, i);

  if(i != valocity) {
    for (i = 0; i < valocity; i = i + 10) {
      analogWrite(PWM, i);
      delay(100);
    }
  }
  Serial.println("forward");
}

void motorStop() {
  digitalWrite(DIR,LOW);
  
  analogWrite(PWM, 0);
  delay(100);
  Serial.println("motorStop");
}

void backward() {
  ////드라이브 모터가 뒤로 회전하도록 신호부여
  digitalWrite(DIR,HIGH); 
  analogWrite(PWM, i);
  
  if(i != valocity) {
    for (i = 0; i < valocity; i = i + 10) {
      analogWrite(PWM, i);
      delay(100);
    }
  }
  Serial.println("backward");
}

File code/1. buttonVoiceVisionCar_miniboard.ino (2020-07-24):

/* 
- 조향 :  
아두이노 UNO - 모터 드라이버(DM322E)  
         p4 - enA 
         p5 - PUL(펄스)  
         p6 - DIR(디렉션)  
모터 드라이버 - 스텝모터(2번, 5번 미사용)  
         A+ - 모터 결선 좌측 1번째  
         A- - 모터 결선 좌측 3번째  
         B+ - 모터 결선 좌측 4번째  
         B- - 모터 결선 좌측 6번째  
모터 드라이버의 점퍼를 조정해 전류를 제어할 수 있음  
모터는 K6G50C 1:50 기어박스가 포함되어 있음  
현재 세팅은 점퍼 스위치 세팅 : 110010 (피크 전류 3.2A, RMS 3.0A, 200pulse/rev)  
- 통신 :  
아두이노 UNO - 블루투스 모듈(HC-06)  
         p2 - TXD  
         p3 - RXD  
- 구동 :  
아두이노 UNO - 모터 드라이버  
전진후진(P10) - dir입력(모터 회전 방향)  
PWM출력(p11) - PWM입력(페달)  
enB(p12) - 구동 여부 결정
- 페달모드 :
아두이노 - 페달
     A0 - 노랑
     7  - 스위치-전진
     8  - 스위치-후진
     9  - ground
*/


#include <SoftwareSerial.h>

SoftwareSerial mySerial(2, 3); // RX, TX

// 스텝 모터 제어
const int dirPinLR = 6;  // 좌우 회전
const int stepPin = 5; // 스텝 펄스
const int enA = 4;  // 구동 여부 결정

const int STEPS_PER_REV = 200; // 모터 1회전 

int rotateLimit = 4;

// 드라이브 모터 제어
const int PWM = 10; // 파워
const int in1 = 11; // 신호 1 
const int in2 = 12; // 신호 2
const int vcc = 13; // 5V 확인용

const int valocity = 100;

// 페달 제어
int pedalF = 7;
boolean pedalFVal = 0;

int pedalB = 8;
boolean pedalBVal = 0;

const int ground = 9;

const int pedalSensor = A0;
int pedalVal = 0;

// 수동 모드, 앱 제어모드 변경, 0은 앱제어모드, 1은 수동 모드
boolean modeState = 1;

// 페달 값
int i = 0;

// 입력 문자
char cmd = "";
char cmdM = "";

void setup() {
  //통신 설정
  Serial.begin(9600); // 시리얼 통신
  mySerial.begin(9600); // 블루투스 통신             

  // 스텝모터 핀 모드 설정
  pinMode(dirPinLR,OUTPUT);
  pinMode(stepPin,OUTPUT); 
  pinMode(enA, OUTPUT);
  digitalWrite(enA, HIGH);


  // 드라이브모터 핀 모드 설정
  pinMode(PWM,OUTPUT);
  pinMode(in1,OUTPUT); 
  pinMode(in2, OUTPUT);
  pinMode(vcc, OUTPUT);
  digitalWrite(vcc, HIGH);
         
  // 페달모드 전진 후진 신호
  pinMode(pedalF, INPUT_PULLUP);
  pinMode(pedalB, INPUT_PULLUP);
  pinMode(ground, OUTPUT);
  digitalWrite(ground, LOW);

  Serial.println("AI Go-Kart is Ready!");
}

void loop() {
  //  modestate가 1이면 페달제어 모드로 수행
  if(modeState == 1) {       
    pedalFVal = digitalRead(pedalF);
    pedalBVal = digitalRead(pedalB);

    pedalVal = analogRead(pedalSensor);
    pedalVal = map(pedalVal, 230, 850, 0, 255);
    pedalVal = constrain(pedalVal, 0, 255);

    Serial.print(pedalFVal);
    Serial.print("  ");
    Serial.print(pedalBVal);
    Serial.print("  ");
    Serial.print(pedalVal);
    Serial.print("  ");

    if (pedalVal == 0) {
      digitalWrite(in1,LOW); 
      digitalWrite(in2,LOW);
      
      analogWrite(PWM, 0);
      delay(100);
    }
    
    if (pedalFVal == 1 && pedalBVal == 0) {
      digitalWrite(in1,HIGH); 
      digitalWrite(in2,LOW); 
      analogWrite(PWM, pedalVal);
      Serial.println("FFFF");
    } else if (pedalFVal == 0 && pedalBVal == 1) {
      digitalWrite(in1,LOW); 
      digitalWrite(in2,HIGH); 
      analogWrite(PWM, pedalVal);
      Serial.println("RRRR");
    } else {
      digitalWrite(in1,LOW); 
      digitalWrite(in2,LOW); 
      analogWrite(PWM, 0);
      Serial.println("SSSS");
    }
  }
         
  if (mySerial.available() ){        // 블루투스 통신에 데이터가 있을 경우
    cmd = mySerial.read();     // 블루투스의 데이터(문자 한 글자)를 'cmd' 변수에 저장
  
    // cmd 변수의 데이터가 m이면 modeState의 상태를 바꿈
    if (cmd == 'm') {
      modeState = !modeState;
      Serial.println("input 'm'");
      Serial.print("mode is : ");
      Serial.println(modeState);
    }
    
    // modestate가 0이면 앱제어 모드로 수행
    if (modeState == 0) {
      if (cmd == 'w' ){               // 만약 'cmd' 변수의 데이터가 q이면
        Serial.println(cmdM);
        if(cmdM == 'w'){
          forward();
        } else {
          i = 0;
          forward();
        }
        cmdM = 'w';
      } else if ( cmd == 'x') {        // 아니고 만약 'cmd' 변수의 데이터가 w면
        if(cmdM == 'x') {
          backward();
        } else {
          i = 0;
          backward();
        }
        cmdM = 'x';
      } else if ( cmd == 'a' ) {       // 아니고 만약 'cmd' 변수의 데이터가 e면
        right();
      } else if ( cmd == 'd' ) {       // 아니고 만약 'cmd' 변수의 데이터가 e면
        left();
      } else if ( cmd == 's' ) {       // 아니고 만약 'cmd' 변수의 데이터가 s면
        motorStop();
      }
    }
  }
}



void left() {
  // 조향 모터가 '반시계방향'으로 회전하도록 신호부여
  digitalWrite(dirPinLR,HIGH); 
  
  if (rotateLimit > 0) {
    // 500마이크로초 주기로 모터 축이 5회전하는 코드
    // 1:50 기어박스 내장되어 있으므로, 모터 1회전에 바퀴 7.2도 회전함
    // 따라서, 모터가 5회전하면 바퀴가 36도 회전함
    for(int x = 0; x < STEPS_PER_REV*1.5; x++) {
      digitalWrite(stepPin,HIGH); 
      delayMicroseconds(1000); 
      digitalWrite(stepPin,LOW); 
      delayMicroseconds(1000); 
    }
    rotateLimit = rotateLimit - 1;
  } else {
    rotateLimit = 0;
  }
  Serial.println(rotateLimit);
}

void right() {
  // 조향 모터가 '시계방향'으로 회전하도록 신호부여
  digitalWrite(dirPinLR,LOW); 
  
  if (rotateLimit < 7) {
    for(int x = 0; x < STEPS_PER_REV*1.5; x++) {
      digitalWrite(stepPin,HIGH); 
      delayMicroseconds(1000); 
      digitalWrite(stepPin,LOW); 
      delayMicroseconds(1000); 
    }
    rotateLimit = rotateLimit + 1;
  } else {
    rotateLimit = 7;
  }
  Serial.println(rotateLimit);
}

void forward() {
  //드라이브 모터가 앞으로 회전하도록 신호부여
  digitalWrite(in1,HIGH); 
  digitalWrite(in2,LOW); 
  analogWrite(PWM, i);

  if(i != valocity) {
    for (i = 0; i < valocity; i = i + 10) {
      analogWrite(PWM, i);
      delay(100);
    }
  }
  Serial.println("forward");
}

void motorStop() {
  digitalWrite(in1,LOW); 
  digitalWrite(in2,LOW);
  
  analogWrite(PWM, 0);
  delay(100);
  Serial.println("motorStop");
}

void backward() {
  ////드라이브 모터가 뒤로 회전하도록 신호부여
  digitalWrite(in1,LOW); 
  digitalWrite(in2,HIGH); 
  analogWrite(PWM, i);
  
  if(i != valocity) {
    for (i = 0; i < valocity; i = i + 10) {
      analogWrite(PWM, i);
      delay(100);
    }
  }
  Serial.println("backward");
}

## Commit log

2020-06-14 Rename stepperMotor.ino to 3. stepperMotor.ino
2020-06-14 Rename buttonAndVoiceCar.ino to 1. buttonAndVoiceCar.ino
2020-06-29 Update 1. buttonAndVoiceCar.ino
2020-07-22 Rename 1. buttonAndVoiceCar.ino to 1. buttonVoiceVisionCar.ino
2020-07-22 Rename 1. buttonVoiceVisionCar.ino to 1. buttonVoiceVisionCar_greenboard.ino
2020-07-22 Create 1. button.ino
2020-07-22 Rename 1. button.ino to buttonVoiceVisionCar_miniboard.ino
2020-07-22 Rename buttonVoiceVisionCar_miniboard.ino to 1. buttonVoiceVisionCar_miniboard.ino
2020-07-22 Update 1. buttonVoiceVisionCar_miniboard.ino
2020-07-24 Rename 1. buttonVoiceVisionCar_greenboard.ino to 2. buttonVoiceVisionCar_greenboard.ino
2020-07-24 Rename 2. buttonVoiceVisionCar_greenboard.ino to ex1. buttonVoiceVisionCar_greenboard.ino
2020-07-24 Create 2. switch.ino
2020-07-24 Update and rename 1. buttonVoiceVisionCar_miniboard.ino to 0. buttonVoiceVisionCar_miniboard.ino
2020-07-24 Rename 0. buttonVoiceVisionCar_miniboard.ino to 6. buttonVoiceVisionCar_miniboard.ino
2020-07-26 Update 6. buttonVoiceVisionCar_miniboard.ino
2020-11-08 Create 7. buttonVoiceVisionCar_miniBoard(LR).ino
2020-11-08 Rename 6. buttonVoiceVisionCar_miniboard.ino to 6. buttonVoiceVisionCar_miniboard(FBSLR).ino
2020-11-08 Update 7. buttonVoiceVisionCar_miniBoard(LR).ino
2021-02-09 Rename ex2. accelCar.ino to ex2. accelerometerCar.ino
2021-02-09 Rename code/2. switch.ino to code/old/2. switch.ino
2021-02-09 Rename code/6. buttonVoiceVisionCar_miniboard(FBSLR).ino to code/old/6. buttonVoiceVisionCar_miniboard(FBSLR).ino
2021-02-09 Rename code/7. buttonVoiceVisionCar_miniBoard(LR).ino to code/old/7. buttonVoiceVisionCar_miniBoard(LR).ino
2021-02-09 Rename code/ex1. buttonVoiceVisionCar_greenboard.ino to code/old/ex1. buttonVoiceVisionCar_greenboard.ino
2021-02-09 Rename code/ex2. accelerometerCar.ino to code/old/ex2. accelerometerCar.ino
2021-04-09 modify file tree
    [AI_Car.fzz]
